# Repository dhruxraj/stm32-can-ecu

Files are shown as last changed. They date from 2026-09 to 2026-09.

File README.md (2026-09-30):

# STM32 CAN ECU – development board (rev A)

A compact, "ECU-style" CAN node for learning and prototyping automotive-type embedded software. It has an STM32G4 MCU, a CAN transceiver with protection and switchable termination, a 6-axis IMU, a protected 8-18 V supply, SWD, a UART, LEDs and buttons.

Two or more identical boards talk to each other over CANH/CANL/GND. Each board broadcasts:

* a heartbeat,
* IMU data,
* supply voltage,
* diagnostics.

Each board also supervises its peers.

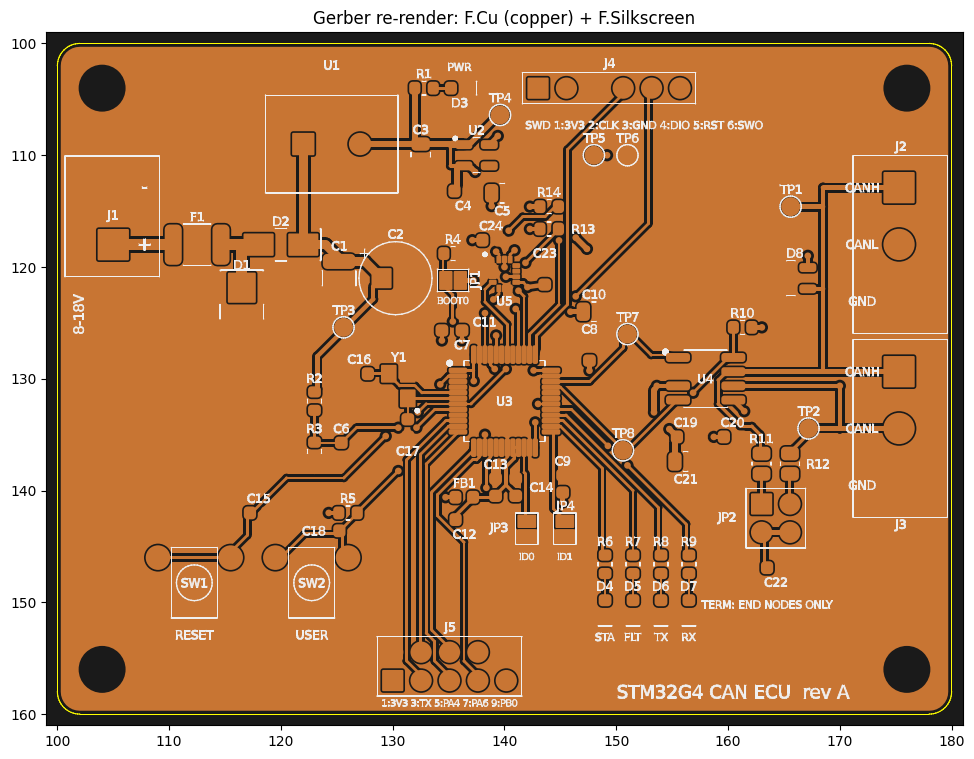
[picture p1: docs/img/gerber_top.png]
PCB


## Quick facts

| | |
|---|---|
| MCU | **STM32G431CBT6** (Cortex-M4F 170 MHz, 128 KB flash, 32 KB RAM, LQFP48) |
| CAN transceiver | **NXP TJA1051T/3** (5 V VCC, 3.3 V VIO), PESD1CAN ESD, split termination on jumper |
| IMU | **ST LSM6DS3TR-C** (accel ±4 g, gyro ±500 dps, I2C 0x6A) |
| Supply | **8-18 V DC** (12 V nominal): PTC + TVS + reverse-polarity diode → RECOM R-78E5.0-0.5 (5 V) → AP2112K-3.3 LDO |
| Power | ≈ 0.35 W typical, < 0.85 W worst case (≈ 28 mA typical / 67 mA worst case at 12 V) |
| PCB | **80 × 60 mm, 4 layers** (signal / GND / 3V3 / signal), 1.6 mm, 4 × M3 |
| CAN | classic CAN 500 kbit/s, 11-bit IDs, counter + CRC-8 on every frame |
| Est. BOM cost | ≈ USD 19 components per board (qty 10, rough estimate) + PCB |
| Tools | KiCad 7/8/9, STM32CubeIDE or CMake + arm-none-eabi-gcc, ST-LINK |

## Repository layout

```
README.md                  this file
docs/                      all documentation (start with BRINGUP.md when your boards arrive)
hardware/kicad/            KiCad project: CAN_ECU.kicad_pro / .kicad_sch / .kicad_pcb + libraries
hardware/fab/              preview Gerbers, drill files, BOM.csv, CPL_top.csv
hardware/gen/              Python generators + independent checkers (how rev A was produced)
firmware/                  STM32Cube HAL firmware (CMake / CubeIDE), host unit tests
tools/                     can_ecu.dbc, Python decoder/monitor (python-can)
```

## Architecture

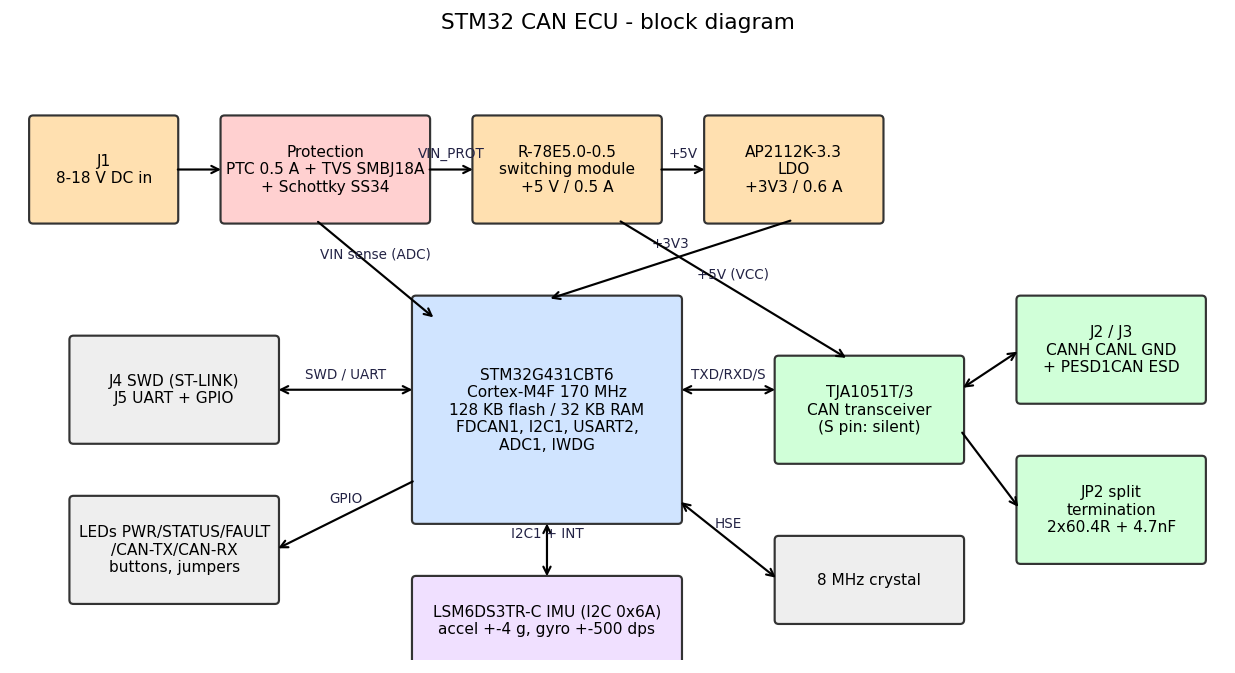
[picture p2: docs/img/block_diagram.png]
block diagram


| Document | Content |
|---|---|
| [docs/DESIGN_NOTES.md](docs/DESIGN_NOTES.md) | architecture, all design decisions, circuit calculations, **assumptions list**, limitations, future work |
| [docs/POWER_CALCS.md](docs/POWER_CALCS.md) | per-rail current budget, regulator dissipation, input current, total power |
| [docs/PIN_MAPPING.md](docs/PIN_MAPPING.md) | all 48 MCU pins, alternate functions, connector and jumper pinouts |
| [docs/COMPONENTS.md](docs/COMPONENTS.md) | component list and footprint list (with **VERIFY** notes) |
| [docs/PCB_LAYOUT.md](docs/PCB_LAYOUT.md) | stack-up, rules, placement and routing strategy |
| [docs/CAN_PROTOCOL.md](docs/CAN_PROTOCOL.md) | IDs, byte layouts, scaling, rates, status bits, counter/CRC, fault bits |
| [docs/FIRMWARE.md](docs/FIRMWARE.md) | module structure, scheduler, robustness features, building, programming |
| [docs/MANUFACTURING.md](docs/MANUFACTURING.md) | fab spec, how to produce/order Gerbers, assembly notes, cost |
| [docs/BRINGUP.md](docs/BRINGUP.md) | step-by-step bring-up, **two-board CAN test**, troubleshooting |
| [docs/TEST_CHECKLIST.md](docs/TEST_CHECKLIST.md) | per-board test sheet |
| [docs/VALIDATION_REPORT.md](docs/VALIDATION_REPORT.md) | results of all automated checks and what could not be checked |

## Hardware overview

* **Power input.** J1 (5.08 mm screw terminal) → F1 PTC 0.5 A → D1 SMBJ18A TVS → D2 SS34 series Schottky → 10 µF + 47 µF → R-78E 5 V module → AP2112K 3.3 V LDO. The MCU's analog supply (VDDA/VREF+) is filtered by FB1. The PWR LED is on +5 V. VIN is measured by the MCU (PA0).
* **MCU.** STM32G431CBT6 with an 8 MHz crystal (PLL 170 MHz) and 100 nF per VDD pin plus 4.7 µF bulk. It has a reset button and SWD header, BOOT0 pull-down plus jumper, and two node-ID jumpers. Unused pins are left unconnected and set to analog.
* **CAN.** FDCAN1 (PA11/PA12) → TJA1051T/3 → PESD1CAN → J2/J3 (1 CANH, 2 CANL, 3 GND, paralleled). JP2 enables the 2 × 60.4 Ω split termination with 4.7 nF to GND. The transceiver's S pin holds it silent until the firmware is ready. Test pads: TP1 CANH, TP2 CANL, TP7 CAN_TX, TP8 CAN_RX.
* **IMU.** LSM6DS3TR-C on I2C1 (PA15/PB7, 4k7 pull-ups), with INT1/INT2 wired to PB5/PB9.
* **User interface.** LEDs STATUS/FAULT/CAN-TX/CAN-RX plus PWR; RESET and USER buttons; J5 2×5 header (3.3 V UART + 5 GPIO/ADC).

## Software overview

* **Firmware.** Bare-metal C using the STM32Cube HAL. A cooperative scheduler runs 10/20/100/1000 ms tasks.
* **CAN.** Interrupt-driven FDCAN RX into a ring buffer, with hardware ID filters and automatic bus-off recovery.
* **Protocol.** IMU data at 50 Hz, heartbeat and board data at 10 Hz, diagnostics at 1 Hz. Every frame carries a rolling counter and a CRC-8.
* **Supervision.** Peer heartbeat timeout of 300 ms. Node states are INIT/RUN/DEGRADED/FAULT, with 13 fault bits (active + latched).
* **Robustness.** Independent watchdog (~1 s), reset-cause reporting, crystal-failure fallback, IMU fault detection with auto re-init.
* **PC side.** `tools/can_monitor.py` (python-can) decodes and verifies all frames and can send commands. `tools/can_ecu.dbc` works in any CAN analyzer.

## Getting started

### 1. Open the design in KiCad

1. Install KiCad 7, 8 or 9.
2. Copy/unzip the project and open **`hardware/kicad/CAN_ECU.kicad_pro`**.
   * Symbols and footprints come from the project-local libraries `CAN_ECU.kicad_sym` / `CAN_ECU.pretty`. They are registered in the project's `sym-lib-table` / `fp-lib-table`, so no library setup is needed.
   * KiCad 8/9 will say the files were made by an older version. Accept; saving converts them.
3. **Schematic:** open the schematic editor and run **Inspect → Electrical Rules Checker**.
4. **PCB:**
   1. Open the PCB editor and press **B** (Fill All Zones). The planes and pours are stored unfilled.
   2. Run **Inspect → Design Rules Checker**. Enable "Test for parity between PCB and schematic".
   3. Use **View → 3D Viewer** for a sanity check. 3D models are not linked, so only footprint outlines appear.

### 2. Order boards

See [docs/MANUFACTURING.md](docs/MANUFACTURING.md). In short:

1. Fill the zones, run DRC and plot Gerbers + drill files from KiCad.
2. Order a 4-layer, 1.6 mm board with ENIG finish.
3. Buy the parts from `hardware/fab/BOM.csv`. Verify the footprints marked **VERIFY** in docs/COMPONENTS.md first.

### 3. Build and flash the firmware

```bash
cd firmware && ./scripts/fetch_st_drivers.sh
cmake -B build -DCMAKE_TOOLCHAIN_FILE=cmake/gcc-arm-none-eabi.cmake && cmake --build build
STM32_Programmer_CLI -c port=SWD mode=UR -w build/can_ecu.hex -v -rst
```

Connect the ST-LINK to J4:

| J4 pin | Signal |
|---|---|
| 1 | VDD (sense) |
| 2 | SWCLK |
| 3 | GND |
| 4 | SWDIO |
| 5 | NRST |
| 6 | SWO |

The board must be powered from J1 while you program it. For the console, use a 3.3 V USB-UART on J5 (pin 3 TX, pin 4 RX, pin 2 GND) at 115200 8N1. CubeIDE instructions are in [docs/FIRMWARE.md](docs/FIRMWARE.md).

### 4. Connect two boards and test CAN

1. Board A: JP3 and JP4 open (**node 0**). Board B: **JP3 closed (node 1)**.
2. On a 2-node bus both boards are bus ends, so **fit both JP2 shunts (1-3 and 2-4) on both boards**. With power off, CANH-CANL must measure ≈ 60 Ω.
3. Wire J2/J3 pin 1-1 (CANH), 2-2 (CANL), 3-3 (GND), using a twisted pair for CANH/CANL.
4. Power both boards (8-18 V).
5. Check the result:
   * Both STATUS LEDs flash at 1 Hz (RUN) and the CAN-TX/RX LEDs flicker.
   * Each UART prints `peer node X online`, and the status line shows the peer's accelerometer values.
   * Pressing USER on one board makes the other blink fast for 3 s.
   * Unplugging the cable gives `PEER_TIMEOUT` (DEGRADED) within 300 ms; the boards recover automatically when you plug it back in.
6. With a USB-CAN adapter, run `python3 tools/can_monitor.py -i socketcan -c can0`. Expect about 121 frames/s per node with zero CRC or counter errors.

The full procedure, expected values and scope checks are in [docs/BRINGUP.md](docs/BRINGUP.md).

## Troubleshooting (short)

| Symptom | Check |
|---|---|
| One board alone shows DEGRADED + `CAN_PASSIVE` | Normal: CAN needs a second node to acknowledge frames. |
| Two boards don't see each other | Node IDs must differ. Check CANH↔CANH / CANL↔CANL wiring, the GND wire, and that termination measures ≈ 60 Ω. |
| `HSI16 FALLBACK` printed | Crystal not starting: check the joints and C16/C17. |
| `IMU_COMM` fault / WHO_AM_I 0x00 | IMU (LGA) soldering, or pull-ups R13/R14. |
| No +3V3 | U2 orientation; a short on +3V3. |
| ST-LINK can't connect | Use "connect under reset"; make sure JP1 (BOOT0) is open. |

More in [docs/BRINGUP.md](docs/BRINGUP.md#5-troubleshooting).

## Validation status (honest summary)

* **PCB design-rule check** (independent checker, 0.2 mm rules): **0 violations, 0 unconnected nets**. Both planes are continuous, and there are no courtyard overlaps.
* **Generated KiCad files re-parsed:**
  * S-expression syntax is valid.
  * The schematic netlist equals the PCB netlist for all 46 nets.
  * The ERC subset passes, and there are no silkscreen collisions.
* **Firmware:** 60 host unit checks pass (protocol, diagnostics, IMU conversion). All sources compile cleanly against a HAL stub, and the Python decoder matches the C golden frames.
* **Not verified here:**
  * KiCad's own ERC/DRC and zone fill (KiCad was not available).
  * A real arm-none-eabi build against the ST HAL.
  * Operation on hardware.
  * Footprints marked VERIFY.

  Details and remaining risks are in [docs/VALIDATION_REPORT.md](docs/VALIDATION_REPORT.md) and [docs/DESIGN_NOTES.md](docs/DESIGN_NOTES.md#4-assumptions-and-items-that-were-not-fully-verified).

## Limitations

This is a development board, **not an automotive-qualified ECU**:

* No ISO 7637 / ISO 16750 load-dump protection.
* No CAN common-mode choke.
* No USB in rev A: it conflicts with the CAN pins on this MCU.
* A single CAN channel.
* The counter/CRC/state machine is AUTOSAR-*inspired*, not compliant.

See [docs/DESIGN_NOTES.md](docs/DESIGN_NOTES.md#5-limitations-of-rev-a).

## Future improvements

* A 2-FDCAN MCU with USB-C.
* A discrete wide-input buck with ideal-diode reverse protection and load-dump rating.
* CAN FD, and a CAN bootloader.
* A CMC footprint.
* UDS-style diagnostics.

See [docs/DESIGN_NOTES.md](docs/DESIGN_NOTES.md#6-future-improvements).

## License

This project uses separate licenses for hardware, software, and documentation.

- **Hardware:** CERN-OHL-P-2.0
- **Firmware and software tools:** MIT License
- **Documentation:** CC BY 4.0

See the corresponding `LICENSE-*` files in the repository for the
complete license terms.

Third-party components retain their original licenses.

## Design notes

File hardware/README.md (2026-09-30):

# Hardware

```
hardware/
  kicad/     KiCad project (open CAN_ECU.kicad_pro) + project symbol/footprint libraries
  fab/       preview Gerbers, drill files, BOM.csv, CPL_top.csv (regenerate from KiCad for ordering)
  gen/       Python generators - the design "source code"
```

`gen/` is how every hardware file in this project was produced. KiCad itself was not available while the files were generated, so they were written by these scripts.

| Script | Purpose |
|---|---|
| `design.py` | parts, values, part numbers and the pin→net netlist (single source of truth) |
| `lib.py` | symbol and footprint definitions |
| `board.py` | board outline and component placement |
| `routing.py` | hand routes, plane fan-out and a constrained router for the low-speed nets |
| `write_kicad.py` | writes the `.kicad_sch/.kicad_pcb/.kicad_pro/.kicad_sym/.pretty` files |
| `checks.py` | independent DRC, connectivity and plane-continuity checks |
| `validate_files.py` | re-parses the written files: syntax, schematic↔PCB netlist, ERC subset, silkscreen |
| `fab.py` | Gerber/Excellon/BOM/CPL + Gerber re-render |
| `gen_docs.py` | pin map, component list, validation report, figures |

Regenerate everything (Python 3.10+, numpy, scipy, matplotlib): `cd hardware/gen && ./build_all.sh`

**Recommended workflow once you own the design:** open the project in KiCad and continue there. KiCad becomes the source of truth from that point, and the generators are then only a record of how rev A was made. Do not mix the two workflows: re-running the generators overwrites manual KiCad edits.

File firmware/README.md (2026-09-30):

# STM32 CAN ECU firmware

STM32G431CBT6 · STM32Cube HAL · C11 · no RTOS. Full documentation is in [`../docs/FIRMWARE.md`](../docs/FIRMWARE.md). The CAN protocol is described in [`../docs/CAN_PROTOCOL.md`](../docs/CAN_PROTOCOL.md).

```bash
./scripts/fetch_st_drivers.sh
cmake -B build -DCMAKE_TOOLCHAIN_FILE=cmake/gcc-arm-none-eabi.cmake -DCMAKE_BUILD_TYPE=Debug
cmake --build build
STM32_Programmer_CLI -c port=SWD mode=UR -w build/can_ecu.hex -v -rst
make -C tests            # host unit tests
```

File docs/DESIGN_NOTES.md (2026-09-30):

# Design notes, decisions and assumptions

## 1. Architecture

block diagram

The board is a small "ECU-style" CAN node:

* **Power:** 8-18 V DC input (12 V nominal). The input is protected by a resettable PTC fuse, a TVS diode and a series Schottky diode. A RECOM R-78E5.0-0.5 switching module makes +5 V. An AP2112K LDO makes +3V3 from +5 V. A ferrite bead and extra capacitors give a filtered +3V3A for the MCU's analog supply (VDDA / VREF+).
* **MCU:** STM32G431CBT6 in LQFP48. It has a Cortex-M4F at 170 MHz, 128 KB flash, 32 KB RAM and one FDCAN (it can be used as classic CAN). It runs from an 8 MHz crystal with the PLL at 170 MHz.
* **CAN:** NXP TJA1051T/3 transceiver. Its VCC is +5 V and its VIO is 3.3 V, so it talks directly to the MCU at 3.3 V logic. The bus has a PESD1CAN ESD diode and a jumper-selectable split termination. Two paralleled 3-pole screw terminals let you daisy-chain boards.
* **Sensor:** ST LSM6DS3TR-C 6-axis IMU on I2C1 (address 0x6A). Its two interrupt lines go to the MCU.
* **Debug and interface:**
  * SWD header in ST-LINK/Nucleo pin order, with SWO.
  * 3.3 V UART plus 5 GPIO on a 2x5 header.
  * 5 LEDs, reset and user buttons.
  * BOOT0 jumper and two node-ID jumpers.

## 2. Key decisions (and why)

| # | Decision | Reason / trade-off |
|---|---|---|
| D1 | **STM32G431CBT6** (G4, not G0) | G0B1/G0C1 also have FDCAN, but the G431 adds FPU, 170 MHz, better ADC and wide availability. The LQFP48 package is hand-solderable at 0.5 mm pitch. |
| D2 | **No USB in rev A** | FDCAN1 is only usable on PA11/PA12, which are also the USB pins. The alternative PB8/PB9 puts CAN_RX on BOOT0, a well-known boot problem. CAN has priority; a UART on J5 replaces USB. |
| D3 | **Input 8-18 V**, not 5-12 V | The CAN transceiver needs 4.5-5.5 V on VCC. A 5 V rail from a 5 V input with protection drops is not possible, and the R-78E module needs >= 7 V in. 12 V automotive-style supply is the target. 5 V input is **not supported**. |
| D4 | Switching module instead of a linear 5 V regulator | 12 V to 5 V at up to 125 mA would waste ~0.9 W in a linear regulator. The pre-certified module needs no layout-critical inductor loop, which suits a first PCB. |
| D5 | 4-layer stack (signal / GND / 3V3 / signal) | This gives a solid reference plane under every trace. It also allows short via-to-plane decoupling, better EMC and easy routing of a 0.5 mm-pitch MCU. Price difference to 2-layer is small at prototype quantities. |
| D6 | TJA1051**T/3** (VIO variant) | The pin 5 VIO gives true 3.3 V logic levels. The plain TJA1051T has pin 5 NC and 5 V RXD output, which is **not** 3.3 V-safe on every MCU pin. Order the **/3** variant. |
| D7 | S pin pulled HIGH (silent) by default | The node stays off the bus until the firmware has configured FDCAN. This avoids disturbing the bus during reset, programming or a crash. |
| D8 | Split termination on a jumper | The bus needs exactly 120 Ω at each physical end: 2 terminations per bus, 60 Ω total. The split 2x60.4 Ω + 4.7 nF to GND also filters common-mode noise (corner ≈ 1.1 MHz). A permanent 120 Ω on every board would give 40 Ω with 3 boards. |
| D9 | Classic CAN 500 kbit/s | Supported by every USB-CAN adapter and analyzer. CAN FD is possible with this MCU/transceiver later (TJA1051 is specified to 5 Mbit/s). |
| D10 | Node ID by solder jumpers | Identical firmware on all boards, no reflashing needed for a second node. |
| D11 | Label-connected single-sheet schematic | Generated programmatically and guaranteed consistent with the PCB netlist. Net labels at every pin make it easy to trace nets in KiCad (click a label to highlight the whole net). |

## 3. Circuit details and small calculations

**HSE crystal (Y1, 8 MHz, CL = 12 pF).**
C = 2 × (CL − C_stray) = 2 × (12 − ~4.5) pF ≈ 15 pF → C16/C17 = 15 pF C0G.
Check the actual crystal's CL and ESR against ST AN2867 (gm_crit margin). A different CL needs different caps.

**Reset.**
NRST has an internal pull-up (~40 kΩ), plus C15 = 100 nF to GND and the SW1 pushbutton. The SWD header carries NRST (pin 5) so the debugger can reset the MCU.

**BOOT0.**
PB8-BOOT0 is pulled down by R4 (10 kΩ) and boots from flash. Closing JP1 enables the ROM bootloader, which the factory option bytes sample (nSWBOOT0 = 1).

**VBAT.**
Tied to +3V3 with its own 100 nF (no RTC battery).

**VDDA / VREF+.**
+3V3 → FB1 (600 Ω @ 100 MHz) → +3V3A with C12 1 µF + C13/C14 100 nF.

**VIN sense.**
R2 100 kΩ / R3 15 kΩ gives a ratio of 7.667. 18 V → 2.35 V at PA0; 25 V → 3.26 V. C6 100 nF gives τ = 1.3 ms. The ADC is referenced to the measured VREFINT, so the result is ratiometric-corrected.

**I2C pull-ups.**
4k7 at 400 kHz with an estimated ≤ 50 pF bus gives t_r ≈ 0.85 × 4.7 kΩ × 50 pF ≈ 0.2 µs. This is below the 0.3 µs Fast-mode limit.

**LED currents.**
(3.3 V − ~2.0 V) / 680 Ω ≈ 1.9 mA, which is enough for modern high-efficiency 0603 LEDs. The power LED gets (5 V − 2 V) / 1k5 = 2 mA.

**CAN ESD.**
PESD1CAN (SOT-23) sits close to the connectors, and the CAN traces pass the diode before reaching the transceiver.

**Reverse polarity.**
The series Schottky D2 blocks reverse voltage. The TVS D1 sits before D2 and is forward-biased on a reversed input, acting as a crowbar. The resulting fault current trips the PTC F1 (hold 0.5 A) within about a second. The board survives, but the supply sees a short until the PTC trips.

## 4. Assumptions and items that were NOT fully verified

| # | Item | Status / action |
|---|---|---|
| A1 | LSM6DS3TR-C LGA-14 land pattern (0.5 × 0.25 mm pads) | Modelled on the typical ST recommendation. **Verify** against the current ST datasheet/TN before ordering. |
| A2 | PESD1CAN pin assignment (1, 2 = lines, 3 = common) | Symmetric device, so a 1↔2 swap is harmless. **Verify pin 3** = common. |
| A3 | R-78E5.0-0.5 pin pitch 2.54 mm and body offset | The keep-out is reserved ±6.5 mm around the pin row. **Verify** against the RECOM drawing. |
| A4 | Screw terminal MPNs (Phoenix 1729128 / 1729131) and hole sizes | **Verify** with the part you buy; any 5.08 mm-pitch terminal with 1.3 mm drill is fine. |
| A5 | Crystal CL 12 pF, 3225 package | Choose a crystal with CL 10-12 pF and ESR ≤ 80 Ω, and recompute C16/C17. |
| A6 | I2C timing 0x10320309 (400 kHz @ HSI16) | Taken from the RM0440 timing example. Verify with CubeMX or measure SCL. |
| A7 | PTC hold 0.5 A / ≥ 30 V rating | Any 1812 PTC with I_hold ≈ 0.5 A and V_max ≥ 30 V. |
| A8 | TVS SMBJ18A clamp 29.2 V @ Ipp vs. R-78E abs. max input | The module is protected against moderate transients only. **Not rated for ISO 7637 / ISO 16750 load dump.** |
| A9 | STM32 current at 170 MHz ≈ 30-40 mA | Datasheet typical run current plus peripherals. The design budget is 100 mA on +3V3. |
| A10 | KiCad file format | Written as KiCad 7 files (opens in KiCad 7/8/9). Not opened in KiCad during generation. See VALIDATION_REPORT.md. |

## 5. Limitations of rev A

* The board is not qualified for vehicles. It has no ISO 7637-2 / ISO 16750-2 load-dump or cold-crank design, no reverse-battery MOSFET and no AEC-Q parts required.
* There is no CAN common-mode choke. One can be added for EMC-critical use.
* There is no USB (see D2). The UART needs a 3.3 V USB-UART adapter.
* Only one CAN channel (the STM32G431 has one FDCAN).
* The E2E-style counter/CRC and state machine are *automotive-inspired*. They are **not** AUTOSAR E2E or ISO 26262 compliant.
* The IMU is not mechanically isolated. Board flex or screw torque can shift the accelerometer offset slightly.

## 6. Future improvements

* Rev B MCU with 2+ FDCAN and separate USB (e.g. STM32G474 / G0B1): gives USB-C device and a second CAN channel.
* Discrete buck (e.g. LMR51420-class) with a reverse-polarity P-FET ideal diode, load-dump TVS and wider 6-36 V input.
* CAN common-mode choke plus split-termination DNP options, and optional CAN FD bit timing (2 Mbit/s data phase).
* EEPROM or option bytes for node configuration, CAN bootloader for field updates, UDS-like diagnostic services.
* Mount the IMU at the board centroid with a stiffening keep-out, and add a temperature compensation table.

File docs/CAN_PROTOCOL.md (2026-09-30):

# CAN protocol (application layer)

Machine-readable versions: `tools/can_ecu.dbc` (all messages, all 4 node IDs) and `tools/canp.py` (Python decoder, identical to `firmware/Core/Src/can_protocol.c`).

## Physical / data link

| Item | Value |
|---|---|
| Bit rate | 500 kbit/s, classic CAN 2.0A (11-bit IDs), no remote frames |
| Bit timing (170 MHz PCLK1) | prescaler 17, TSEG1 15, TSEG2 4, SJW 4 → 20 tq, **sample point 80 %** |
| Termination | 120 Ω at both physical ends (JP2 fitted on those two boards only) |
| Transceiver | TJA1051T/3, VCC 5 V, VIO 3.3 V, S pin = silent while MCU not ready |
| Connector | J2 / J3: 1 = CANH, 2 = CANL, 3 = GND (paralleled, for daisy-chaining) |

## Identifiers

`ID = 0x100 + (node << 4) + message`, node = 0..3 from jumpers JP3/JP4.

| Message | Offset | Node 0 | Node 1 | Node 2 | Node 3 | Period | Direction |
|---|---:|---:|---:|---:|---:|---:|---|
| HEARTBEAT | 0 | 0x100 | 0x110 | 0x120 | 0x130 | 100 ms | ECU → bus |
| ACCEL | 1 | 0x101 | 0x111 | 0x121 | 0x131 | 20 ms | ECU → bus |
| GYRO | 2 | 0x102 | 0x112 | 0x122 | 0x132 | 20 ms | ECU → bus |
| BOARD | 3 | 0x103 | 0x113 | 0x123 | 0x133 | 100 ms | ECU → bus |
| DIAG | 4 | 0x104 | 0x114 | 0x124 | 0x134 | 1000 ms | ECU → bus |
| COMMAND to node n | - | 0x0F0 | 0x0F1 | 0x0F2 | 0x0F3 | event | any → node |
| COMMAND broadcast | - | 0x0FF | | | | event | any → all |

Lower ID means higher priority: commands win arbitration over data, and heartbeats over sensor data of the same node.

Bus load per node is 121 frames/s (10 + 50 + 50 + 10 + 1). At ≤ 130 bits per 8-byte frame including worst-case bit stuffing, that is ≈ 16 kbit/s ≈ **3 % of 500 kbit/s**. Four nodes use about 13 %.

## Common frame rules

* **DLC** = 8 always. Frames with another DLC are rejected and counted as errors.
* **Byte order:** little-endian (Intel). Signed values are two's complement.
* **Byte 6:** bits 0-3 are the **rolling counter** (0…15, +1 per message ID). Bits 4-7 are the **status nibble**:
  * bit 4 `DATA_VALID`
  * bit 5 `SENSOR_FAULT`
  * bit 6 `DEGRADED`
  * bit 7 reserved
* **Byte 7:** **CRC-8 SAE J1850** (poly 0x1D, init 0xFF, final XOR 0xFF). It is computed over `[ID & 0xFF, (ID >> 8) & 0x07, byte0 … byte6]`, so the ID is protected as well. Check value: CRC("123456789") = 0x4B.
* **Receiver checks** (`canp_check()`):
  * DLC == 8, then CRC.
  * Counter equal to the previous one → *repeated/stale* frame, rejected.
  * Counter jump → frames lost, accepted but counted.
  * CRC, DLC or repeat errors set fault `CAN_E2E` for 1 s.

> This counter + CRC scheme is inspired by AUTOSAR E2E profiles. It is **not** an implementation of any AUTOSAR E2E profile and is not safety-certified.

## Message layouts

### HEARTBEAT (0x100 + node·16), 100 ms

| Byte | Signal | Type | Unit / values |
|---|---|---|---|
| 0 | node_id | u8 | 0..3 |
| 1 | state | u8 | 0 INIT, 1 RUN, 2 DEGRADED, 3 FAULT |
| 2-3 | faults | u16 | active fault bits (table below) |
| 4 | peers_alive | u8 | bit n = heartbeat of node n received within 300 ms |
| 5 | fw_version | u8 | major << 4 \| minor (0x10 = 1.0) |
| 6 | counter / status | | status bit 6 = DEGRADED |
| 7 | CRC | | |

### ACCEL (+1) and GYRO (+2), 20 ms

| Byte | Signal | Type | Scaling | Range |
|---|---|---|---|---|
| 0-1 | X | s16 | ACCEL: 1 mg/bit; GYRO: 0.1 °/s/bit | ±4000 mg; ±500 °/s |
| 2-3 | Y | s16 | as above | |
| 4-5 | Z | s16 | as above | |
| 6 | counter / status | | DATA_VALID, SENSOR_FAULT | |
| 7 | CRC | | | |

The sensor is sampled at 104 Hz ODR and read every 20 ms. The firmware converts the raw sensor LSBs to these physical units (0.122 mg/LSB, 17.5 mdps/LSB). When the IMU is faulty, frames keep being sent (last values, `DATA_VALID` = 0, `SENSOR_FAULT` = 1), so receivers can tell "sensor fault" from "node lost".

### BOARD (+3), 100 ms

| Byte | Signal | Type | Scaling |
|---|---|---|---|
| 0-1 | vin | u16 | 1 mV/bit |
| 2-3 | imu_temp | s16 | 0.01 °C/bit |
| 4-5 | uptime | u16 | 1 s/bit (wraps at 65535 s) |

### DIAG (+4), 1000 ms

| Byte | Signal | Meaning |
|---|---|---|
| 0 | TEC | FDCAN transmit error counter |
| 1 | REC | FDCAN receive error counter |
| 2 | proto_flags | bit0 error-warning, bit1 error-passive, bit2 bus-off, bits 3-5 last error code (LEC) |
| 3 | busoff_count | saturating at 255 |
| 4 | e2e_errors | received CRC/DLC/repeat errors since last clear (saturating) |
| 5 | reset_cause | 0 unknown, 1 power-on/BOR, 2 pin, 3 software, 4 IWDG, 5 WWDG, 6 low-power, 7 option-byte |

### COMMAND (0x0F0 + target, or 0x0FF broadcast)

| Byte | Signal | Values |
|---|---|---|
| 0 | command | 1 IDENTIFY (STATUS LED blinks fast for 3 s), 2 CLEAR_FAULTS (clear latched fault history) |
| 1 | source node | 0..3, 0x0F = PC tool |
| 2 | argument | reserved (0) |
| 3-5 | reserved | 0 |
| 6-7 | counter / CRC | as for all frames |

A short press of the USER button sends IDENTIFY broadcast. A long press (≥ 2 s) clears local faults and broadcasts CLEAR_FAULTS.

## Fault bits (heartbeat bytes 2-3)

| Bit | Name | Set when | Cleared when |
|---:|---|---|---|
| 0 | IMU_COMM | WHO_AM_I wrong / I2C error | IMU re-init succeeds (retried every 1 s) |
| 1 | IMU_DATA | 50 identical samples (stuck) or all-zero accel | data plausible again |
| 2 | CAN_BUSOFF | FDCAN bus-off (**critical → state FAULT**) | automatic recovery done |
| 3 | CAN_PASSIVE | error-passive (e.g. alone on the bus, no ACK) | counters decrease |
| 4 | PEER_TIMEOUT | a peer seen before sends no heartbeat for 300 ms | peer back |
| 5 | CAN_E2E | CRC / DLC / repeated-counter error received | 1 s without errors |
| 6 | VIN_LOW | VIN < 7.5 V | VIN > 7.8 V |
| 7 | VIN_HIGH | VIN > 18.5 V | VIN < 18.0 V |
| 8 | HSE | crystal failed (CSS) → running from HSI16 ±1 % | reset |
| 9 | WDG_RESET | last reset by watchdog (latched only) | CLEAR_FAULTS |
| 10 | CAN_TX_OVF | TX FIFO full, frame dropped | 1 s without overflow |
| 11 | MCU_TEMP | die temperature > 100 °C | < 100 °C |
| 12 | ID_CONFLICT | a frame with our own node ID was received | CLEAR_FAULTS/reset |

**State machine:**

* INIT: stays in INIT for at least 200 ms and until all drivers are initialised.
* FAULT: if any critical fault is active.
* DEGRADED: if any other fault is active.
* RUN: otherwise.

"Latched" faults (history since power-up or the last CLEAR_FAULTS) are shown by a slow FAULT-LED blink.

## Example frames (golden vectors, verified in C and Python)

```
0x110  01 01 00 00 01 10 03 3A   HEARTBEAT node 1, RUN, no faults, peers 0x01, fw 1.0, counter 3, CRC 0x3A
0x101  0C 00 DD FF E6 03 17 7E   ACCEL node 0: X = 12 mg, Y = -35 mg, Z = 998 mg, DATA_VALID, counter 7
```

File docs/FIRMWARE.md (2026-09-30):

# Firmware

`firmware/` is an STM32Cube HAL project in C11 for the STM32G431CBT6. No RTOS is used.

## Module structure

| File | Responsibility |
|---|---|
| `Core/Src/main.c` | Start-up sequence, clock tree (HSE→PLL 170 MHz, HSI16 fallback, clock-security system), reset-cause capture, watchdog, main loop |
| `Core/Src/board.c` / `board.h` | Pin map, GPIO init (unused pins → analog), LEDs, button, node-ID jumpers, transceiver S pin, ADC (VIN, VREFINT, die temperature) |
| `Core/Src/can.c` / `can.h` | FDCAN1: 500 kbit/s timing, RX filters, interrupt RX into a lock-free ring buffer, TX FIFO queue, error counters, **bus-off recovery** |
| `Core/Src/can_protocol.c` / `.h` | Pure-C protocol: IDs, payload packing, rolling counter, CRC-8, receive checks, peer timeout (host unit-tested) |
| `Core/Src/imu.c` / `imu.h` | LSM6DS3TR-C: WHO_AM_I, soft reset, configuration, burst read, unit conversion, stuck/implausible detection, automatic re-init |
| `Core/Src/diagnostics.c` / `.h` | Fault bits, active/latched handling, VIN hysteresis, node state machine (host unit-tested) |
| `Core/Src/app.c` / `app.h` | Cooperative scheduler, CAN message handling, commands, LED patterns, button, UART status output |
| `Core/Src/debug.c` | USART2 115200 8N1 console; `printf` via `_write` |
| `Core/Src/stm32g4xx_it.c`, `stm32g4xx_hal_msp.c` | Interrupt handlers (SysTick, FDCAN1_IT0, NMI/CSS, faults) and peripheral clock/pin/NVIC setup |
| `Core/Inc/stm32g4xx_hal_conf.h` | HAL module selection, HSE_VALUE = 8 MHz |
| `STM32G431CBTX_FLASH.ld` | Linker script (128 KB flash, 32 KB RAM) |
| `CMakeLists.txt`, `cmake/` | arm-none-eabi-gcc build |
| `tests/` | Host unit tests + compile check of all sources against HAL stubs |

## Scheduler and timing

The scheduler runs on the 1 ms `HAL_GetTick()`, cooperatively and without blocking. All HAL calls have timeouts of 20 ms or less.

| Period | Work |
|---|---|
| 10 ms | drain CAN RX queue (max 16 frames), FDCAN status + bus-off recovery, fault flags, state machine, button, LEDs |
| 20 ms | IMU read (or re-init attempt once per second when faulty), ACCEL + GYRO frames |
| 100 ms | VIN measurement, peer heartbeat supervision (300 ms timeout), HEARTBEAT + BOARD frames |
| 1000 ms | MCU temperature, DIAG frame, one UART status line |

## Robustness features ("automotive-style", not certified)

* **Watchdog:**
  * The IWDG runs at about 1 s (LSI/32, reload 1000) and is frozen while the debugger halts the core.
  * It is refreshed only if the 10 ms task ran within the last 100 ms. A stuck loop, a HardFault or `Error_Handler()` therefore causes a reset.
  * A watchdog reset is latched as fault `WDG_RESET` and reported in DIAG.
* **Reset cause:** read from RCC_CSR at start-up and sent in DIAG.
* **Clock monitoring:**
  * If the crystal does not start, the PLL is built from HSI16 at the same 170 MHz, so the CAN timing is unchanged.
  * The clock security system (NMI) catches a crystal failure at run time.
  * Both cases set fault `HSE`, because HSI accuracy (±1 %) is marginal for CAN.
* **CAN bus handling:**
  * RX filters accept only 0x100-0x13F plus own and broadcast commands.
  * Error-warning, error-passive and bus-off are monitored.
  * Bus-off is recovered automatically: after 100 ms the firmware clears CCCR.INIT, and the controller then waits for 128×11 recessive bits.
  * The TX FIFO fill level is checked before sending; overflow is flagged.
  * The transceiver stays silent until FDCAN is running.
* **End-to-end-style checks:** rolling counter + CRC-8 on every frame, DLC check, repeated-frame detection, lost-frame counting, 300 ms heartbeat timeout per peer, detection of a second node with the same ID.
* **Sensor faults:**
  * WHO_AM_I and register read-back at init.
  * I2C error counting.
  * Stuck-data detection (50 identical samples) and all-zero detection.
  * Automatic re-initialisation every 1 s.
  * Invalid data is still transmitted but marked `DATA_VALID = 0` / `SENSOR_FAULT = 1`.
* **Supply monitoring:** VIN is measured against VREFINT with hysteresis, and the die temperature is checked.

## LED indication

| LED | Pattern | Meaning |
|---|---|---|
| PWR (D3, green) | on | +5 V present |
| STATUS (D4, green) | 5 Hz blink | INIT |
| | 1 Hz short flash | RUN |
| | 2 Hz blink | DEGRADED |
| | off | FAULT |
| | 10 Hz for 3 s | IDENTIFY received |
| FAULT (D5, red) | on | active fault |
| | short flash every 2 s | only latched (past) faults |
| | off | no faults |
| CAN TX (D6) | flicker | frame transmitted |
| CAN RX (D7) | flicker | frame received |

## Building

### Option A - CMake + GNU Arm toolchain (Linux/macOS/Windows)

```bash
cd firmware
./scripts/fetch_st_drivers.sh        # clones ST's HAL + CMSIS from github.com/STMicroelectronics
cmake -B build -DCMAKE_TOOLCHAIN_FILE=cmake/gcc-arm-none-eabi.cmake -DCMAKE_BUILD_TYPE=Debug
cmake --build build                  # -> build/can_ecu.elf, .hex, .bin
```

Requires `arm-none-eabi-gcc` (Arm GNU Toolchain 12 or newer), CMake ≥ 3.20 and git.

### Option B - STM32CubeIDE

1. Go to **File → New → STM32 Project**, pick **STM32G431CBTx**, and choose an empty C project with the STM32Cube firmware package.
2. Delete the generated `Core/Src/main.c` and `Core/Inc/main.h`.
3. Copy every file from `firmware/Core/Inc` and `firmware/Core/Src` into the project's `Core/Inc` and `Core/Src`, overwriting `stm32g4xx_hal_conf.h`, `stm32g4xx_it.*` and `stm32g4xx_hal_msp.c`.
4. Make sure the HAL drivers for ADC, FDCAN, I2C, IWDG and UART are present in `Drivers/STM32G4xx_HAL_Driver`. Copy them from the STM32CubeG4 package if the wizard did not add them.
5. Delete CubeIDE's `syscalls.c` **or** our `_write()` in `debug.c`. Keep only one `_write`.
6. Build with Project → Build, then Run → Debug with the ST-LINK.

### Host tests (any PC with gcc)

```bash
make -C firmware/tests      # 60 unit checks (ASan/UBSan) + stub-HAL compile of every source file
python3 tools/test_tools.py # Python decoder == C golden vectors, DBC layout check
```

> **Honest status:** the protocol, diagnostics and IMU-conversion logic were compiled and unit-tested on a PC. Every other source file was compiled with `-Wall -Wextra -Werror` against a minimal HAL *stub*. The firmware was **not** built with arm-none-eabi-gcc against the real ST HAL, and not run on hardware, in the generation environment. Expect possible small compile fixes if your HAL version differs; the code avoids version-specific details (for example, `DataLength` is handled for both HAL encodings).

## Programming

1. Connect an ST-LINK V2/V3 (or a Nucleo board's ST-LINK with its CN2 jumpers removed) to **J4**:

   | J4 pin | Signal |
   |---|---|
   | 1 | VDD_TARGET (sense only) |
   | 2 | SWCLK |
   | 3 | GND |
   | 4 | SWDIO |
   | 5 | NRST |
   | 6 | SWO |

   Pin 1 is the square pad.
2. Power the board from J1 (12 V). The ST-LINK does **not** power the board.
3. Flash:
   * **STM32CubeProgrammer:** `STM32_Programmer_CLI -c port=SWD mode=UR -w build/can_ecu.hex -v -rst`
   * **OpenOCD:** `openocd -f interface/stlink.cfg -f target/stm32g4x.cfg -c "program build/can_ecu.elf verify reset exit"`
   * **CubeIDE:** Run/Debug.
4. Console: connect a 3.3 V USB-UART to J5.
   * J5 pin 3 (board TX) → adapter RX.
   * J5 pin 4 (board RX) ← adapter TX.
   * J5 pin 2 → GND.
   * Settings: 115200 8N1.

**Fallback without ST-LINK:**

1. Close JP1 (BOOT0) and reset.
2. Use STM32CubeProgrammer over UART on PA2/PA3: `-c port=/dev/ttyUSB0`. USART2 is a bootloader interface on G431 — **verify against ST AN2606 (STM32G431 section)**.
3. Open JP1 again afterwards.

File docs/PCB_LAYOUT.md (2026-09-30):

# PCB layout

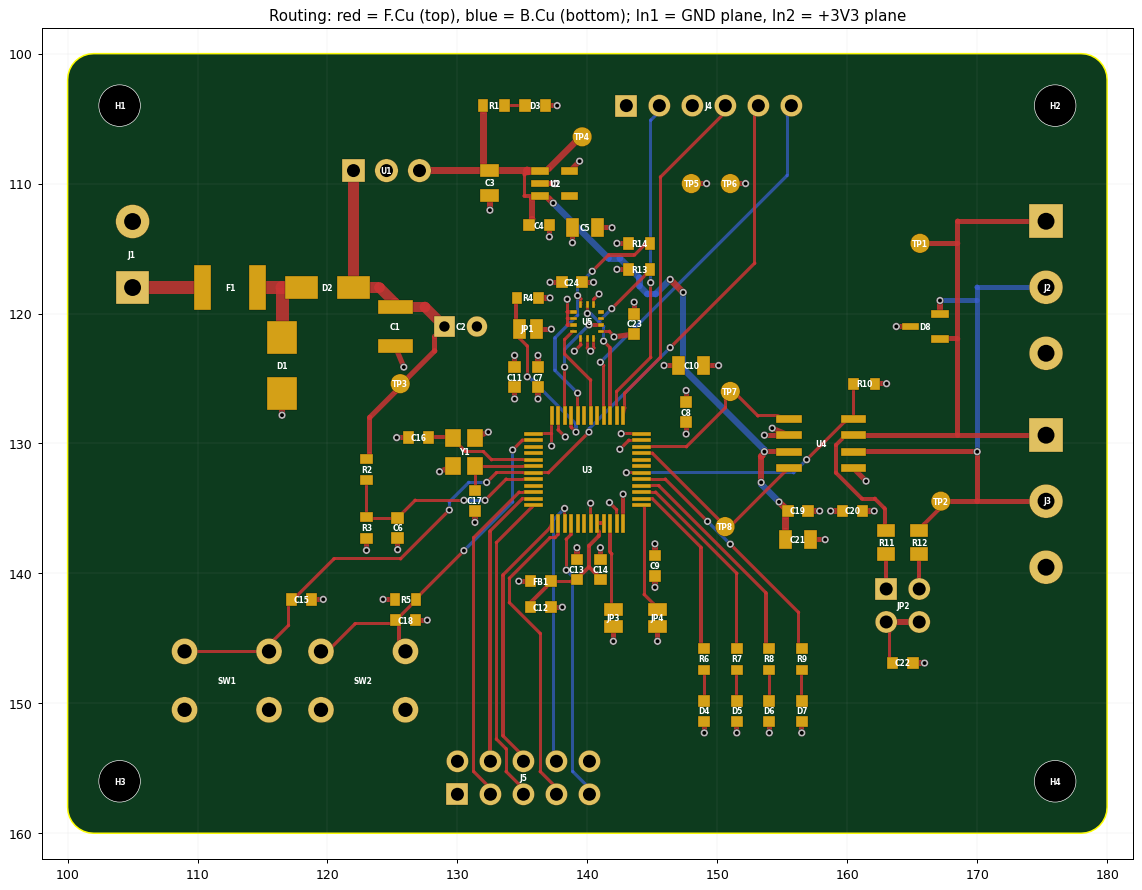
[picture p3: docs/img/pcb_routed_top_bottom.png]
routed board


| Item | Value |
|---|---|
| Size | **80 × 60 mm**, 2 mm corner radius, 4 × M3 holes (3.2 mm NPTH) at 4 mm from the edges |
| Stack-up | **4 layers, 1.6 mm, 1 oz outer / 0.5-1 oz inner** |
| Layers | F.Cu = components + signals + GND pour; **In1.Cu = solid GND plane**; **In2.Cu = +3V3 plane**; B.Cu = signals + GND pour |
| Rules | 0.20 mm clearance, 0.25 mm default track, 0.6/0.3 mm vias, 0.3 mm copper-to-edge, 0.25 mm zone clearance |
| Net classes | Default 0.25 mm; Power 0.5 mm (VIN 0.8-1.0 mm); CAN 0.4 mm |
| Assembly | all components on the top side; SMD 0603 minimum, one LGA-14 (IMU) and one 0.5 mm-pitch LQFP |

## Placement

* **Left edge:** J1 power input with F1 → D2 → C1/C2 → R-78E module in a straight left-to-right chain. The 1.0 mm / 0.8 mm VIN traces are on F.Cu, and TVS D1 sits right after the fuse.
* **Centre:** MCU (U3) with the crystal Y1 and its 15 pF caps directly left of OSC_IN/OSC_OUT (short, symmetric, over solid GND). The IMU (U5) sits just above the MCU.
* **Right edge:** CAN section.
  * U4 transceiver has TXD/RXD facing the MCU and CANH/CANL facing the connectors.
  * The ESD diode D8 and split termination R11/R12/C22/JP2 are next to the J2/J3 terminals.
  * CANH/CANL run as a pair (0.4 mm) from U4 to both connectors, over the GND plane.
* **Top:** SWD header J4 and the power LED. **Bottom:** J5 expansion header, the RESET/USER buttons and the 4 status LEDs with silkscreen labels.

## Routing approach

* **Hand-routed (explicit coordinates in `hardware/gen/routing.py`):** power chain, +5 V to the LDO, the CAN trunk to both connectors, the transceiver supply vias, and all MCU/IMU supply connections.
* **MCU supply connections:** the MCU supply pins connect *inward* to vias under the LQFP body. The escape area around the chip is then free for signals, and every VDD/VSS pin has its own via into the planes 0.2 mm below.
* **Other GND/+3V3 SMD pads:** each has its own short stub and via to the plane ("fan-out").
* **Remaining low-speed nets:** routed one at a time in a chosen priority order by a constrained grid router: 45° routing, turn and via penalties, exact clearance to real pad/track geometry. The order is crystal first, then CAN TX/RX, analog supply, IMU, SWD, LEDs, jumpers, expansion, then +5 V. Every result was checked by the independent DRC in `checks.py`.
* **Result:** 384 track segments, 103 vias, 0 clearance violations, 0 unconnected nets. Both planes are continuous for all their connections.

## Things to check in KiCad before ordering

1. Open `CAN_ECU.kicad_pcb` and press **B** (fill all zones). Then run **Inspect → Design Rules Checker**.
   * Expected result: no errors.
   * Silkscreen warnings may remain where reference texts touch other silk. Adjust them to taste.
2. Run **Inspect → Board Statistics** and check the layer stack in **Board Setup → Physical Stackup**. Set the stack-up your fab offers (e.g. JLC04161H-7628 or equivalent).
3. Look at thermal reliefs on the GND pads of J1, J2/J3 and the R-78E. KiCad's defaults (0.3 mm gap / 0.4 mm spokes) are fine for hand soldering.

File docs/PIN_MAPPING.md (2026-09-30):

# MCU pin mapping - STM32G431CBT6 (LQFP48)

Generated from `hardware/gen/design.py` (single source of truth for schematic, PCB and firmware `Core/Inc/board.h`). Pin numbers/names were checked against ST datasheet DS12589 (LQFP48 pinout). Unused pins are unconnected on the PCB and configured as analog inputs by the firmware.

| Pin | Name | Net | Function |
|---:|---|---|---|
| 1 | VBAT | +3V3 | +3V3 (no backup battery), 100 nF |
| 2 | PC13 | USER_BTN | USER button SW2 (active low, ext. 10k pull-up) |
| 3 | PC14-OSC32_IN | - | not connected (analog input) |
| 4 | PC15-OSC32_OUT | - | not connected (analog input) |
| 5 | PF0-OSC_IN | OSC_IN | HSE 8 MHz crystal Y1 |
| 6 | PF1-OSC_OUT | OSC_OUT | HSE 8 MHz crystal Y1 |
| 7 | PG10-NRST | NRST | Reset: SW1, C15 100 nF, SWD pin 5 |
| 8 | PA0 | VIN_SENSE | ADC1_IN1 - VIN sense divider 100k/15k |
| 9 | PA1 | - | not connected (analog input) |
| 10 | PA2 | UART_TX | USART2_TX (AF7) debug console -> J5.3 |
| 11 | PA3 | UART_RX | USART2_RX (AF7) debug console -> J5.4 |
| 12 | PA4 | EXP_PA4 | Expansion J5.5 (GPIO/ADC/DAC) |
| 13 | PA5 | EXP_PA5 | Expansion J5.6 |
| 14 | PA6 | EXP_PA6 | Expansion J5.7 |
| 15 | PA7 | EXP_PA7 | Expansion J5.8 |
| 16 | PB0 | EXP_PB0 | Expansion J5.9 |
| 17 | PB1 | - | not connected (analog input) |
| 18 | PB2 | - | not connected (analog input) |
| 19 | VSSA | GND | GND |
| 20 | VREF+ | +3V3A | +3V3A, 100 nF |
| 21 | VDDA | +3V3A | +3V3A (ferrite FB1 + 1 uF + 100 nF) |
| 22 | PB10 | NODE_ID0 | NODE_ID bit0 - solder jumper JP3 to GND (internal pull-up) |
| 23 | VSS | GND | GND |
| 24 | VDD | +3V3 | +3V3, 100 nF per pin + 4.7 uF bulk |
| 25 | PB11 | NODE_ID1 | NODE_ID bit1 - solder jumper JP4 to GND (internal pull-up) |
| 26 | PB12 | LED_STATUS | LED STATUS (green) via 680R |
| 27 | PB13 | LED_FAULT | LED FAULT (red) via 680R |
| 28 | PB14 | LED_CANTX | LED CAN-TX (yellow) via 680R |
| 29 | PB15 | LED_CANRX | LED CAN-RX (orange) via 680R |
| 30 | PA8 | CAN_S | CAN transceiver S (silent) - 10k pull-up, LOW = normal |
| 31 | PA9 | - | not connected (analog input) |
| 32 | PA10 | - | not connected (analog input) |
| 33 | PA11 | CAN_RX | FDCAN1_RX (AF9) <- TJA1051 RXD |
| 34 | PA12 | CAN_TX | FDCAN1_TX (AF9) -> TJA1051 TXD |
| 35 | VSS | GND | GND |
| 36 | VDD | +3V3 | +3V3, 100 nF per pin + 4.7 uF bulk |
| 37 | PA13 | SWDIO | SWDIO (J4.4) |
| 38 | PA14 | SWCLK | SWCLK (J4.2) |
| 39 | PA15 | I2C_SCL | I2C1_SCL (AF4) - IMU, 4k7 pull-up |
| 40 | PB3 | SWO | SWO trace output (J4.6) |
| 41 | PB4 | - | not connected (analog input) |
| 42 | PB5 | IMU_INT1 | IMU INT1 (accel data-ready) |
| 43 | PB6 | - | not connected (analog input) |
| 44 | PB7 | I2C_SDA | I2C1_SDA (AF4) - IMU, 4k7 pull-up |
| 45 | PB8-BOOT0 | BOOT0 | BOOT0: 10k pull-down, JP1 to 3V3 = system bootloader |
| 46 | PB9 | IMU_INT2 | IMU INT2 (spare) |
| 47 | VSS | GND | GND |
| 48 | VDD | +3V3 | +3V3, 100 nF per pin + 4.7 uF bulk |

## Alternate-function summary

| Peripheral | Signal | Pin | AF |
|---|---|---|---|
| FDCAN1 | RX | PA11 | AF9 |
| FDCAN1 | TX | PA12 | AF9 |
| I2C1 | SCL | PA15 | AF4 |
| I2C1 | SDA | PB7 | AF4 |
| USART2 | TX | PA2 | AF7 |
| USART2 | RX | PA3 | AF7 |
| SWD | SWDIO / SWCLK / SWO | PA13 / PA14 / PB3 | AF0 (reset default) |
| ADC1 | IN1 (VIN sense) | PA0 | analog |

**Why no USB:** on the STM32G431 the only FDCAN1 pin pair that does not collide with other functions here is PA11/PA12 - the same pins as USB DM/DP. The alternative FDCAN1 pins PB8/PB9 would put CAN RX on the BOOT0 pin (PB8), which is a known source of boot problems. Rev A therefore uses PA11/PA12 for CAN and provides a 3.3 V UART on J5 instead of USB.

## Connectors

### J1 - Power input (5.08 mm screw terminal)

| Pin | Net |
|---:|---|
| 1 | VIN_RAW |
| 2 | GND |

### J2 - CAN bus A (5.08 mm, 3-pole)

| Pin | Net |
|---:|---|
| 1 | CANH |
| 2 | CANL |
| 3 | GND |

### J3 - CAN bus B (5.08 mm, 3-pole, parallel to J2 for daisy-chaining)

| Pin | Net |
|---:|---|
| 1 | CANH |
| 2 | CANL |
| 3 | GND |

### J4 - SWD debug (1x6 2.54 mm, ST-LINK/Nucleo CN4 order)

| Pin | Net |
|---:|---|
| 1 | +3V3 |
| 2 | SWCLK |
| 3 | GND |
| 4 | SWDIO |
| 5 | NRST |
| 6 | SWO |

### J5 - Expansion / UART (2x5 2.54 mm)

| Pin | Net |
|---:|---|
| 1 | +3V3 |
| 2 | GND |
| 3 | UART_TX |
| 4 | UART_RX |
| 5 | EXP_PA4 |
| 6 | EXP_PA5 |
| 7 | EXP_PA6 |
| 8 | EXP_PA7 |
| 9 | EXP_PB0 |
| 10 | GND |

### JP2 - CAN termination (2x2 2.54 mm, fit 2 shunts: 1-3 and 2-4)

| Pin | Net |
|---:|---|
| 1 | TERM_H |
| 2 | TERM_L |
| 3 | TERM_MID |
| 4 | TERM_MID |

## Jumpers

| Ref | Function | Open (default) | Closed |
|---|---|---|---|
| JP1 | BOOT0 | boot from flash | ST system bootloader (UART/FDCAN/I2C/SPI) |
| JP2 | CAN termination (2 shunts) | no termination | 2 x 60.4 R split + 4.7 nF |
| JP3 | NODE_ID bit 0 (PB10) | 0 | 1 |
| JP4 | NODE_ID bit 1 (PB11) | 0 | 1 |

Node ID = JP4*2 + JP3 -> 0..3. Two boards must have **different** node IDs (e.g. board A: both open = node 0; board B: JP3 closed = node 1).

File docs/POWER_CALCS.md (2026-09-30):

# Power budget and dissipation

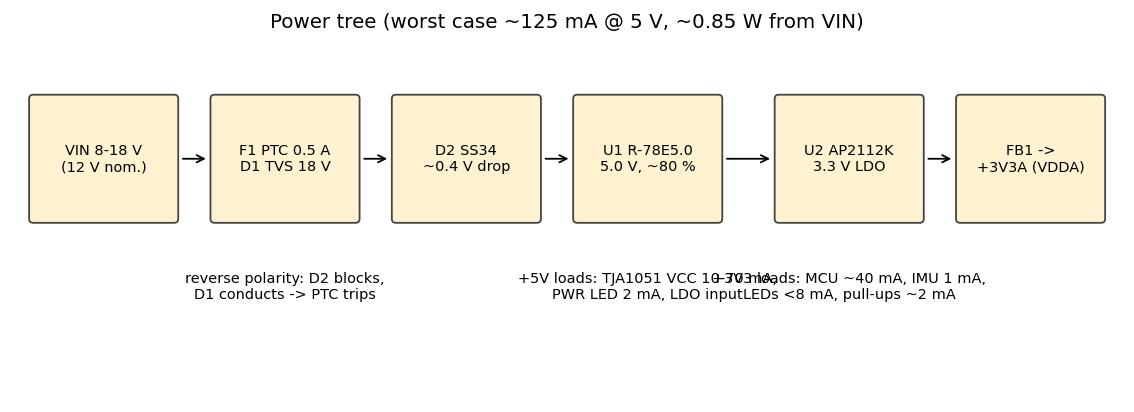
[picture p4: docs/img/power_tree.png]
power tree


## +3V3 rail (AP2112K-3.3, 600 mA rated)

| Load | Typical | Worst case | Note |
|---|---:|---:|---|
| STM32G431 @ 170 MHz, FDCAN+I2C+UART+ADC active | 30 mA | 40 mA | datasheet run-mode typical + peripherals |
| LSM6DS3TR-C (XL + G, 104 Hz high-performance) | 0.9 mA | 1.3 mA | |
| 4 status LEDs @ ~1.9 mA | 2 mA | 7.6 mA | typical = blinking duty cycle |
| I2C pull-ups (2 × 3.3 V / 4k7 when low) | 0.2 mA | 1.4 mA | |
| TJA1051 VIO, CAN_S pull-up (0.33 mA when S low), button pull-up | 0.5 mA | 1.0 mA | |
| **Total +3V3** | **≈ 34 mA** | **≈ 52 mA** | design budget 100 mA |

LDO dissipation, which scales with (5.0 − 3.3) V × I:

* At the 52 mA worst-case load: **88 mW**.
* At the 100 mA budget: **170 mW**.

With θJA ≈ 250 °C/W (SOT-23-5 on a 4-layer board, conservative) the temperature rise is +22 °C at worst case and +43 °C at the 100 mA budget. Both are fine.

## +5V rail (R-78E5.0-0.5, 500 mA rated)

| Load | Typical | Worst case | Note |
|---|---:|---:|---|
| TJA1051 VCC | 15 mA | 70 mA | 10 mA recessive / 50 typ-70 max mA dominant; typical at ~15 % bus load; worst = continuous dominant (bus fault) |
| Power LED D3 | 2 mA | 2 mA | |
| AP2112K input (= +3V3 load + 55 µA Iq) | 34 mA | 52 mA | |
| **Total +5V** | **≈ 51 mA** | **≈ 124 mA** | ≈ 25 % of module rating |

P_5V: typical 0.26 W, worst case 0.62 W.

## Input (VIN, 8-18 V)

The input power is estimated with:

* Module efficiency η ≈ 80 % at this light load. This is conservative; check the RECOM efficiency curve.
* Schottky D2 drop ≈ 0.35-0.45 V.

| VIN | P_in typical | I_in typical | P_in worst | I_in worst |
|---|---:|---:|---:|---:|
| 8 V | 0.34 W | 42 mA | 0.82 W | 103 mA |
| 12 V | 0.34 W | 28 mA | 0.80 W | 67 mA |
| 18 V | 0.33 W | 19 mA | 0.79 W | 44 mA |

**Total board power is ≈ 0.35 W typical and < 0.85 W worst case.**

Loss breakdown, worst case:

* Module: ≈ 0.16 W
* LDO: 0.09 W
* D2: 0.04 W
* TJA1051 (dominant): ≈ 0.2 W
* MCU: 0.13 W

Nothing needs a heatsink.

## Protection ratings

* **F1 PTC (hold 0.5 A):** normal current is ≤ 0.1 A, so the margin is 5×. It trips on a crowbar (reverse polarity) or a short.
* **D1 SMBJ18A:** V_RWM 18 V (maximum continuous input), V_BR ≥ 20 V, V_C 29.2 V @ 20.5 A.
* **D2 SS34:** 3 A / 40 V. Its reverse rating blocks a reversed 18 V input with margin.
* **C1:** 10 µF / 50 V X7R 1210.
* **C2:** 47 µF / 35 V electrolytic. It damps cable inductance ringing on hot-plug. It is **below** the module's 220 µF maximum capacitive load on the output side, and on the input side there is no limit.

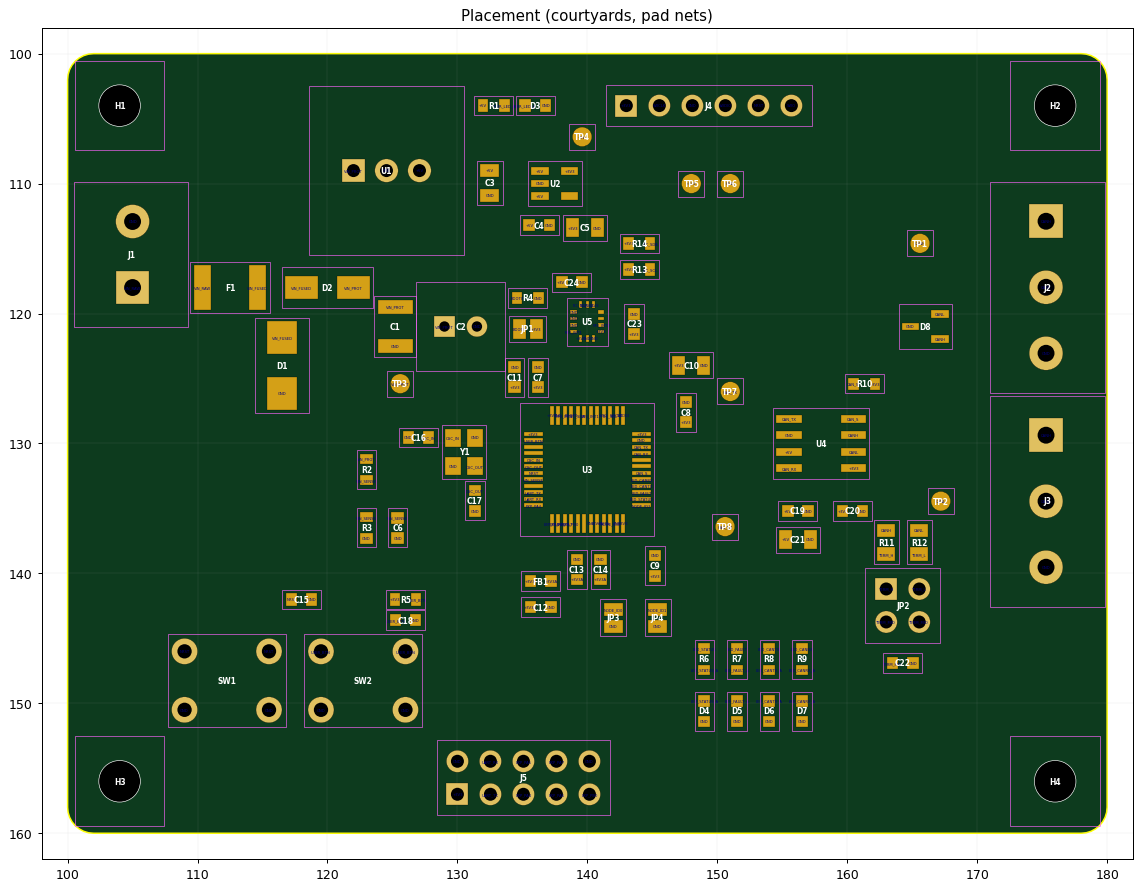
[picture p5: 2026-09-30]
docs/img/pcb_placement.png

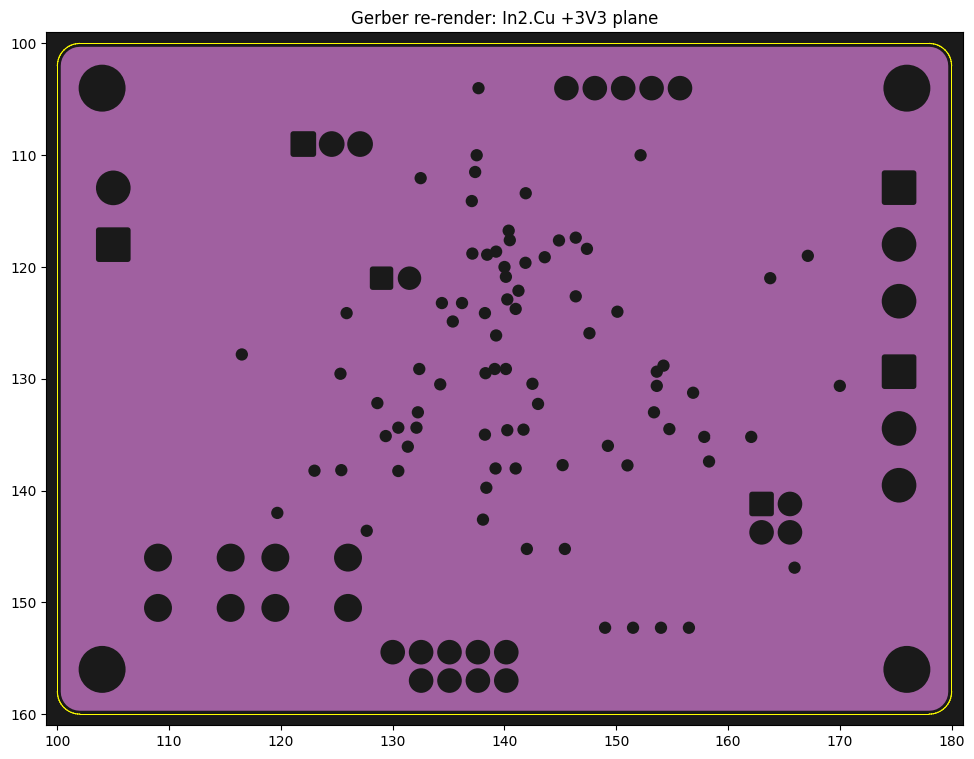
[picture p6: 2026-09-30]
docs/img/gerber_in2_3v3.png

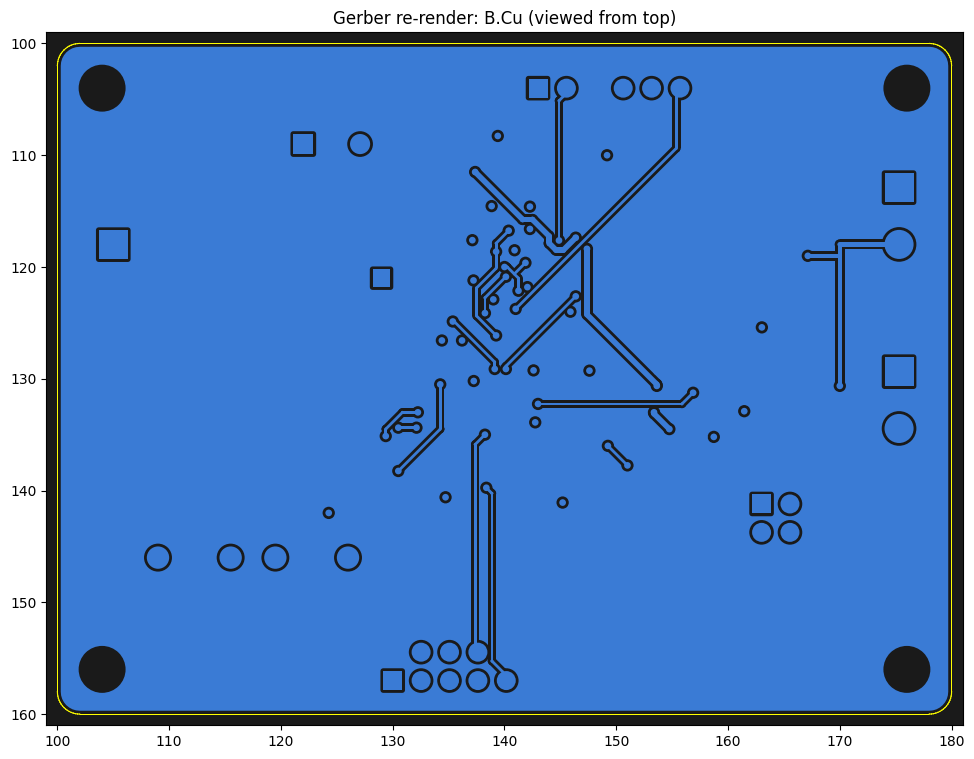
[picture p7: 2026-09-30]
docs/img/gerber_bottom.png

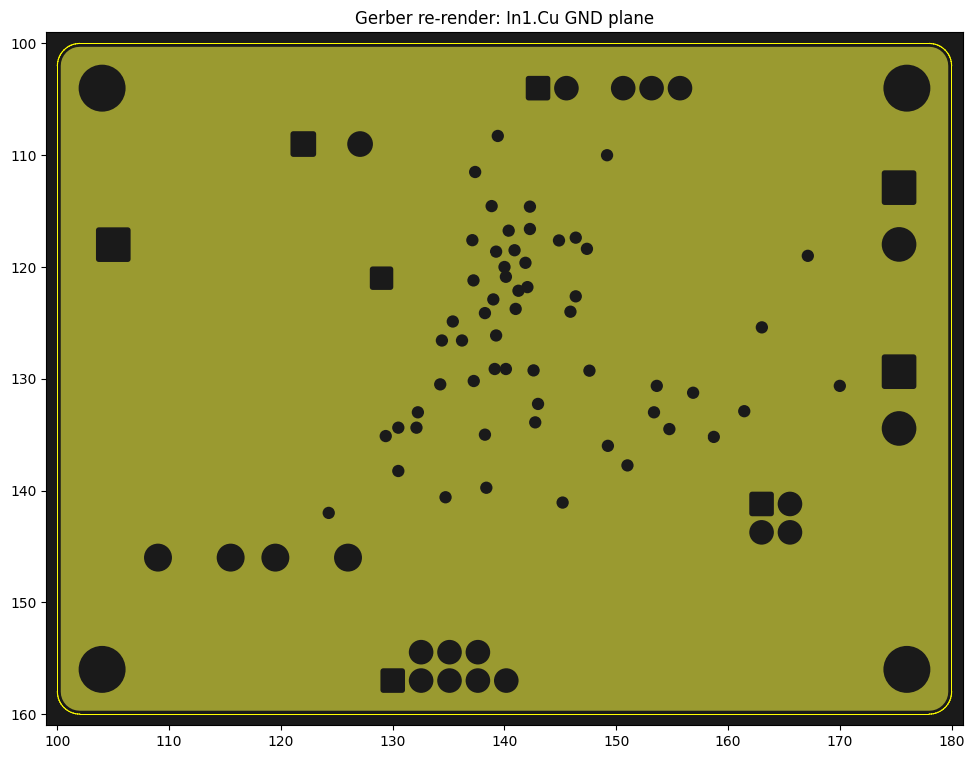
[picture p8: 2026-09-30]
docs/img/gerber_in1_gnd.png

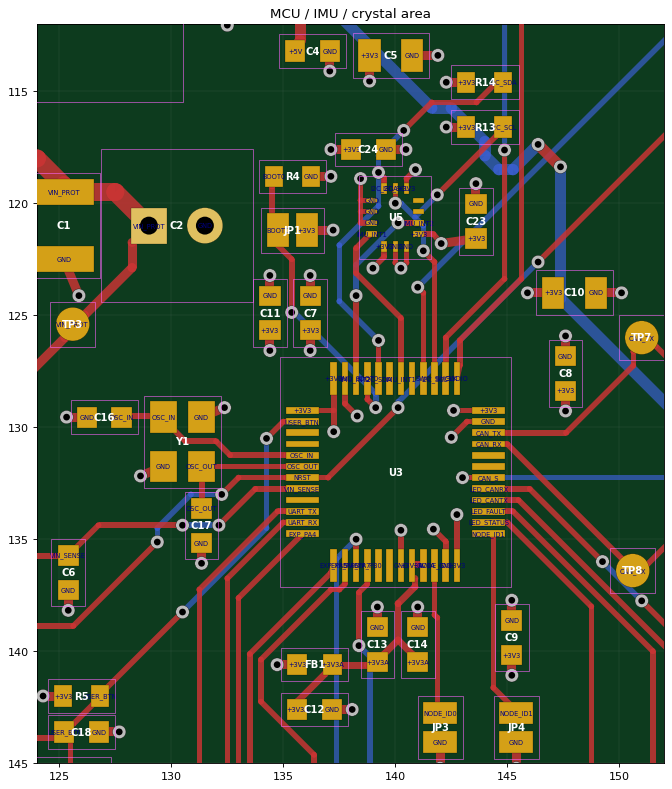
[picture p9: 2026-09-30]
docs/img/pcb_zoom_mcu.png

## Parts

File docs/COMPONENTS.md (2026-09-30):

# Component and footprint list

Generated from `hardware/gen/design.py` and `lib.py`. All footprints live in the project library `hardware/kicad/CAN_ECU.pretty` (self-contained project); the column *KiCad std* names the equivalent footprint in KiCad's official libraries, which you may swap in. Rows marked **VERIFY** must be checked against the manufacturer drawing of the exact part you buy before ordering PCBs.

## Components

| Ref | Value | Part / specification | Footprint | Function |
|---|---|---|---|---|
| C1 | 10uF 50V X7R | -  | C_1210_3225Metric | Input ceramic 10 uF 50 V X7R 1210 |
| C2 | 47uF 35V | 47 uF 35 V aluminium electrolytic, D6.3 mm, P2.5 mm, low-ESR  | CP_Radial_D6.3mm_P2.50mm | Input bulk / damping capacitor |
| C3 | 10uF 16V X5R | -  | C_0805_2012Metric | 5 V rail output capacitor 0805 |
| C4 | 1uF 16V X7R | -  | C_0603_1608Metric | LDO input capacitor |
| C5 | 10uF 10V X5R | -  | C_0805_2012Metric | LDO output capacitor |
| C6 | 100nF | -  | C_0603_1608Metric | Ceramic capacitor 100nF, 0603 |
| C7 | 100nF | -  | C_0603_1608Metric | VDD pin 48 decoupling |
| C8 | 100nF | -  | C_0603_1608Metric | VDD pin 36 decoupling |
| C9 | 100nF | -  | C_0603_1608Metric | VDD pin 24 decoupling |
| C10 | 4.7uF 10V X5R | -  | C_0805_2012Metric | VDD bulk |
| C11 | 100nF | -  | C_0603_1608Metric | VBAT decoupling |
| C12 | 1uF 16V X7R | -  | C_0603_1608Metric | VDDA bulk |
| C13 | 100nF | -  | C_0603_1608Metric | VDDA decoupling |
| C14 | 100nF | -  | C_0603_1608Metric | VREF+ decoupling |
| C15 | 100nF | -  | C_0603_1608Metric | NRST filter |
| C16 | 15pF C0G | -  | C_0603_1608Metric | HSE load cap (for CL = 12 pF crystal) |
| C17 | 15pF C0G | -  | C_0603_1608Metric | HSE load cap (for CL = 12 pF crystal) |
| C18 | 100nF | -  | C_0603_1608Metric | User button debounce |
| C19 | 100nF | -  | C_0603_1608Metric | Transceiver VCC decoupling |
| C20 | 100nF | -  | C_0603_1608Metric | Transceiver VIO decoupling |
| C21 | 4.7uF 16V X5R | -  | C_0805_2012Metric | Transceiver VCC bulk |
| C22 | 4.7nF 50V | -  | C_0603_1608Metric | Split termination common-mode capacitor |
| C23 | 100nF | -  | C_0603_1608Metric | IMU VDD decoupling |
| C24 | 100nF | -  | C_0603_1608Metric | IMU VDDIO decoupling |
| D1 | SMBJ18A | SMBJ18A (Littelfuse) | D_SMB | 600 W unidirectional TVS, VRWM 18 V, SMB |
| D2 | SS34 | SS34 (onsemi/various) | D_SMA | 3 A 40 V Schottky, reverse-polarity protection, SMA |
| D3 | GREEN PWR | 0603 green LED, Vf~2.0 V  | LED_0603_1608Metric | Power indicator (5 V rail) |
| D4 | GREEN STATUS | 0603 green LED  | LED_0603_1608Metric | STATUS indicator |
| D5 | RED FAULT | 0603 red LED  | LED_0603_1608Metric | FAULT indicator |
| D6 | YELLOW CAN-TX | 0603 yellow LED  | LED_0603_1608Metric | CAN-TX indicator |
| D7 | ORANGE CAN-RX | 0603 orange LED  | LED_0603_1608Metric | CAN-RX indicator |
| D8 | PESD1CAN | PESD1CAN,215 (Nexperia) | SOT-23 | CAN bus ESD protection, SOT-23 (verify pinout: 1,2 = bus lines, 3 = GND) |
| F1 | PTC 0.5A/30V | 1812 PTC, Ihold 0.5 A, Vmax >= 30 V (e.g. Bourns MF-MSMF series - select 30 V rated) (Bourns/Littelfuse) | Fuse_1812_4532Metric | Resettable PTC fuse, 1812 |
| FB1 | 600R@100MHz | BLM18AG601SN1D (or equiv. 0603 bead, >=200 mA) (Murata) | L_0603_1608Metric | VDDA filter bead |
| H1 | M3 | - (-) | MountingHole_3.2mm_M3 | M3 mounting hole (NPTH) |
| H2 | M3 | - (-) | MountingHole_3.2mm_M3 | M3 mounting hole (NPTH) |
| H3 | M3 | - (-) | MountingHole_3.2mm_M3 | M3 mounting hole (NPTH) |
| H4 | M3 | - (-) | MountingHole_3.2mm_M3 | M3 mounting hole (NPTH) |
| J1 | PWR_IN 8-18V | 1729128 (MKDS 1,5/ 2-5,08) or equivalent (Phoenix Contact) | TerminalBlock_1x02_P5.08mm_Horizontal | 2-pos 5.08 mm PCB screw terminal, power input (1 = +VIN, 2 = GND) |
| J2 | CAN | 1729131 (MKDS 1,5/ 3-5,08) or equivalent (Phoenix Contact) | TerminalBlock_1x03_P5.08mm_Horizontal | CAN bus connector (1 = CANH, 2 = CANL, 3 = GND); J2/J3 are paralleled for daisy-chain |
| J3 | CAN | 1729131 (MKDS 1,5/ 3-5,08) or equivalent (Phoenix Contact) | TerminalBlock_1x03_P5.08mm_Horizontal | CAN bus connector (1 = CANH, 2 = CANL, 3 = GND); J2/J3 are paralleled for daisy-chain |
| J4 | SWD | 1x6 2.54 mm pin header  | PinHeader_1x06_P2.54mm_Vertical | SWD: 1 VDD_TARGET, 2 SWCLK, 3 GND, 4 SWDIO, 5 NRST, 6 SWO (Nucleo CN4 order) |
| J5 | EXPANSION | 2x5 2.54 mm pin header  | PinHeader_2x05_P2.54mm_Vertical | Expansion / debug UART (USART2) |
| JP1 | BOOT0 | - (-) | SolderJumper-2_P1.3mm_Open_Pad1.0x1.5mm | Close to force ST system bootloader |
| JP2 | CAN_TERM | 2x2 2.54 mm header + 2 jumper shunts  | PinHeader_2x02_P2.54mm_Vertical | Termination enable: fit BOTH shunts (1-3 and 2-4) on end-of-bus nodes only |
| JP3 | NODE_ID0 | - (-) | SolderJumper-2_P1.3mm_Open_Pad1.0x1.5mm | Node-ID bit 0 (closed = 1) |
| JP4 | NODE_ID1 | - (-) | SolderJumper-2_P1.3mm_Open_Pad1.0x1.5mm | Node-ID bit 1 (closed = 1) |
| R1 | 1k5 | -  | R_0603_1608Metric | Resistor 1k5, 0603, 1%, thick film |
| R2 | 100k 1% | -  | R_0603_1608Metric | VIN divider top, 1% |
| R3 | 15k 1% | -  | R_0603_1608Metric | VIN divider bottom, 1% |
| R4 | 10k | -  | R_0603_1608Metric | BOOT0 pull-down (boot from Flash) |
| R5 | 10k | -  | R_0603_1608Metric | User button pull-up |
| R6 | 680R | -  | R_0603_1608Metric | Resistor 680R, 0603, 1%, thick film |
| R7 | 680R | -  | R_0603_1608Metric | Resistor 680R, 0603, 1%, thick film |
| R8 | 680R | -  | R_0603_1608Metric | Resistor 680R, 0603, 1%, thick film |
| R9 | 680R | -  | R_0603_1608Metric | Resistor 680R, 0603, 1%, thick film |
| R10 | 10k | -  | R_0603_1608Metric | Transceiver S pull-up: SILENT until firmware enables |
| R11 | 60R4 1% | -  | R_0805_2012Metric | Split termination 60.4R 0805 |
| R12 | 60R4 1% | -  | R_0805_2012Metric | Split termination 60.4R 0805 |
| R13 | 4k7 | -  | R_0603_1608Metric | I2C SCL pull-up |
| R14 | 4k7 | -  | R_0603_1608Metric | I2C SDA pull-up |
| SW1 | RESET | 6x6 mm THT tactile switch  | SW_PUSH_6mm | Reset push-button |
| SW2 | USER | 6x6 mm THT tactile switch  | SW_PUSH_6mm | User push-button |
| TP1 | CANH | - (-) | TestPoint_Pad_D1.5mm | Test pad CANH |
| TP2 | CANL | - (-) | TestPoint_Pad_D1.5mm | Test pad CANL |
| TP3 | VIN_PROT | - (-) | TestPoint_Pad_D1.5mm | Test pad VIN_PROT |
| TP4 | +5V | - (-) | TestPoint_Pad_D1.5mm | Test pad +5V |
| TP5 | +3V3 | - (-) | TestPoint_Pad_D1.5mm | Test pad +3V3 |
| TP6 | GND | - (-) | TestPoint_Pad_D1.5mm | Test pad GND |
| TP7 | CAN_TX | - (-) | TestPoint_Pad_D1.5mm | Test pad CAN_TX |
| TP8 | CAN_RX | - (-) | TestPoint_Pad_D1.5mm | Test pad CAN_RX |
| U1 | R-78E5.0-0.5 | R-78E5.0-0.5 (RECOM) | Converter_DCDC_RECOM_R-78E-0.5_THT | 5 V 0.5 A non-isolated switching regulator module, 7-28 V in, SIP-3 |
| U2 | AP2112K-3.3 | AP2112K-3.3TRG1 (Diodes Inc.) | SOT-23-5 | 3.3 V 600 mA LDO, SOT-23-5 |
| U3 | STM32G431CBT6 | STM32G431CBT6 (STMicroelectronics) | LQFP-48_7x7mm_P0.5mm | Cortex-M4F 170 MHz, 128 KB Flash, 32 KB RAM, FDCAN, LQFP48 |
| U4 | TJA1051T/3 | TJA1051T/3,118 (NXP) | SOIC-8_3.9x4.9mm_P1.27mm | High-speed CAN (FD) transceiver with VIO, SO8. Must be the /3 (VIO) variant! |
| U5 | LSM6DS3TR-C | LSM6DS3TR-C (STMicroelectronics) | LGA-14_3x2.5mm_P0.5mm_LayoutBorder3x4y | 6-axis IMU (accel + gyro), I2C addr 0x6A |
| Y1 | 8MHz CL12pF | 8.000 MHz, 3225 4-pad, +-20 ppm, CL = 12 pF (ESR <= 100R)  | Crystal_SMD_3225-4Pin_3.2x2.5mm | HSE crystal for accurate CAN bit timing |

## Footprints

| Project footprint | KiCad std equivalent | Type | Used by | Verification note |
|---|---|---|---|---|
| R_0603_1608Metric | Resistor_SMD:R_0603_1608Metric | smd | R1 R2 R3 R4 R5 R6 R7 R8 R9 R10 R13 R14 | Standard generic land pattern. |
| C_0603_1608Metric | Capacitor_SMD:C_0603_1608Metric | smd | C4 C6 C7 C8 C9 C11 C12 C13 C14 C15 C16 C17 C18 C19 C20 C22 C23 C24 | Standard generic land pattern. |
| L_0603_1608Metric | Inductor_SMD:L_0603_1608Metric | smd | FB1 | Standard generic land pattern. |
| C_0805_2012Metric | Capacitor_SMD:C_0805_2012Metric | smd | C3 C5 C10 C21 | Standard generic land pattern. |
| R_0805_2012Metric | Resistor_SMD:R_0805_2012Metric | smd | R11 R12 | Standard generic land pattern. |
| C_1210_3225Metric | Capacitor_SMD:C_1210_3225Metric | smd | C1 | Standard generic land pattern. |
| Fuse_1812_4532Metric | Fuse:Fuse_1812_4532Metric | smd | F1 | Generic 1812 PTC land pattern. |
| D_SMA | Diode_SMD:D_SMA | smd | D2 | Standard generic land pattern. |
| D_SMB | Diode_SMD:D_SMB | smd | D1 | Standard generic land pattern. |
| LED_0603_1608Metric | LED_SMD:LED_0603_1608Metric | smd | D3 D4 D5 D6 D7 | Standard generic land pattern. |
| SOIC-8_3.9x4.9mm_P1.27mm | Package_SO:SOIC-8_3.9x4.9mm_P1.27mm | smd | U4 | Standard JEDEC MS-012 land pattern. |
| LQFP-48_7x7mm_P0.5mm | Package_QFP:LQFP-48_7x7mm_P0.5mm | smd | U3 | Generated to IPC-7351-like dimensions (pads 1.475 x 0.3 at +-4.1625). Compare with KiCad Package_QFP:LQFP-48_7x7mm_P0.5mm. |
| SOT-23 | Package_TO_SOT_SMD:SOT-23 | smd | D8 | **VERIFY** PESD1CAN pinout (1 = CANH/line, 2 = CANL/line, 3 = common) - symmetric part, swapping 1/2 is harmless. |
| SOT-23-5 | Package_TO_SOT_SMD:SOT-23-5 | smd | U2 | AP2112K SOT-23-5 pinout checked (1 VIN, 2 GND, 3 EN, 4 NC, 5 VOUT). |
| LGA-14_3x2.5mm_P0.5mm_LayoutBorder3x4y | Package_LGA:LGA-14_3x2.5mm_P0.5mm_LayoutBorder3x4y | smd | U5 | **VERIFY** against ST LSM6DS3TR-C land-pattern recommendation (pads 0.5 x 0.25 mm). Pin-1 orientation is critical. |
| Crystal_SMD_3225-4Pin_3.2x2.5mm | Crystal:Crystal_SMD_3225-4Pin_3.2x2.5mm | smd | Y1 | Standard 3225 4-pad; confirm pad 1/3 = crystal, 2/4 = GND for the chosen part. |
| TerminalBlock_1x02_P5.08mm_Horizontal | TerminalBlock_Phoenix:TerminalBlock_Phoenix_MKDS-1,5-2-5.08_1x02_P5.08mm_Horizontal | through_hole | J1 | **VERIFY** hole size/pitch vs. the terminal block actually bought (Phoenix MKDS 1,5/2-5,08 style). |
| TerminalBlock_1x03_P5.08mm_Horizontal | TerminalBlock_Phoenix:TerminalBlock_Phoenix_MKDS-1,5-3-5.08_1x03_P5.08mm_Horizontal | through_hole | J2 J3 | **VERIFY** as above (3-pole). |
| PinHeader_1x06_P2.54mm_Vertical | Connector_PinHeader_2.54mm:PinHeader_1x06_P2.54mm_Vertical | through_hole | J4 | Standard generic land pattern. |
| PinHeader_2x05_P2.54mm_Vertical | Connector_PinHeader_2.54mm:PinHeader_2x05_P2.54mm_Vertical | through_hole | J5 | Standard generic land pattern. |
| PinHeader_2x02_P2.54mm_Vertical | Connector_PinHeader_2.54mm:PinHeader_2x02_P2.54mm_Vertical | through_hole | JP2 | Standard generic land pattern. |
| SW_PUSH_6mm | Button_Switch_THT:SW_PUSH_6mm | through_hole | SW1 SW2 | Standard generic land pattern. |
| Converter_DCDC_RECOM_R-78E-0.5_THT | Converter_DCDC:Converter_DCDC_RECOM_R-78E-0.5_THT | through_hole | U1 | **VERIFY** pin pitch (2.54 mm) and body side against the RECOM drawing; 6.5 mm keep-out reserved both sides. |
| CP_Radial_D6.3mm_P2.50mm | Capacitor_THT:CP_Radial_D6.3mm_P2.50mm | through_hole | C2 | Standard generic land pattern. |
| SolderJumper-2_P1.3mm_Open_Pad1.0x1.5mm | Jumper:SolderJumper-2_P1.3mm_Open_Pad1.0x1.5mm | smd | JP1 JP3 JP4 | Standard generic land pattern. |
| TestPoint_Pad_D1.5mm | TestPoint:TestPoint_Pad_D1.5mm | smd | TP1 TP2 TP3 TP4 TP5 TP6 TP7 TP8 | Standard generic land pattern. |
| MountingHole_3.2mm_M3 | MountingHole:MountingHole_3.2mm_M3 | exclude | H1 H2 H3 H4 | Standard generic land pattern. |

## BOM

See `hardware/fab/BOM.csv` (grouped, with rough cost estimates).

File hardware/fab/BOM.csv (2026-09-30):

Item | Qty | References | Value | Footprint (project lib) | Equivalent KiCad std footprint | MPN / specification | Manufacturer | Description | Mount | Est. unit USD | Est. ext. USD
1 | 1 | C1 | 10uF 50V X7R | C_1210_3225Metric | Capacitor_SMD:C_1210_3225Metric | generic 10uF 50V X7R, 1210 | any | Input ceramic 10 uF 50 V X7R 1210 | SMD | 0.35 | 0.35
2 | 1 | C2 | 47uF 35V | CP_Radial_D6.3mm_P2.50mm | Capacitor_THT:CP_Radial_D6.3mm_P2.50mm | 47 uF 35 V aluminium electrolytic, D6.3 mm, P2.5 mm, low-ESR | any | Input bulk / damping capacitor | THT | 0.20 | 0.20
3 | 1 | C3 | 10uF 16V X5R | C_0805_2012Metric | Capacitor_SMD:C_0805_2012Metric | generic 10uF 16V X5R, 0805 | any | 5 V rail output capacitor 0805 | SMD | 0.08 | 0.08
4 | 2 | C4 C12 | 1uF 16V X7R | C_0603_1608Metric | Capacitor_SMD:C_0603_1608Metric | generic 1uF 16V X7R, 0603 | any | LDO input capacitor; VDDA bulk | SMD | 0.03 | 0.06
5 | 1 | C5 | 10uF 10V X5R | C_0805_2012Metric | Capacitor_SMD:C_0805_2012Metric | generic 10uF 10V X5R, 0805 | any | LDO output capacitor | SMD | 0.08 | 0.08
6 | 13 | C6 C7 C8 C9 C11 C13 C14 C15 C18 C19 C20 C23 C24 | 100nF | C_0603_1608Metric | Capacitor_SMD:C_0603_1608Metric | generic 100nF, 0603 | any | Ceramic capacitor 100nF, 0603; IMU VDD decoupling; IMU VDDIO decoupling; NRST filter; Transceiver VCC decoupling; Transceiver VIO decoupling; User button debounce; VBAT decoupling; VDD pin 24 decoupling; VDD pin 36 decoupling; VDD pin 48 decoupling; VDDA decoupling; VREF+ decoupling | SMD | 0.02 | 0.26
7 | 1 | C10 | 4.7uF 10V X5R | C_0805_2012Metric | Capacitor_SMD:C_0805_2012Metric | generic 4.7uF 10V X5R, 0805 | any | VDD bulk | SMD | 0.06 | 0.06
8 | 2 | C16 C17 | 15pF C0G | C_0603_1608Metric | Capacitor_SMD:C_0603_1608Metric | generic 15pF C0G, 0603 | any | HSE load cap (for CL = 12 pF crystal) | SMD | 0.03 | 0.06
9 | 1 | C21 | 4.7uF 16V X5R | C_0805_2012Metric | Capacitor_SMD:C_0805_2012Metric | generic 4.7uF 16V X5R, 0805 | any | Transceiver VCC bulk | SMD | 0.06 | 0.06
10 | 1 | C22 | 4.7nF 50V | C_0603_1608Metric | Capacitor_SMD:C_0603_1608Metric | generic 4.7nF 50V, 0603 | any | Split termination common-mode capacitor | SMD | 0.03 | 0.03
11 | 1 | D1 | SMBJ18A | D_SMB | Diode_SMD:D_SMB | SMBJ18A | Littelfuse | 600 W unidirectional TVS, VRWM 18 V, SMB | SMD | 0.25 | 0.25
12 | 1 | D2 | SS34 | D_SMA | Diode_SMD:D_SMA | SS34 | onsemi/various | 3 A 40 V Schottky, reverse-polarity protection, SMA | SMD | 0.15 | 0.15
13 | 1 | D3 | GREEN PWR | LED_0603_1608Metric | LED_SMD:LED_0603_1608Metric | 0603 green LED, Vf~2.0 V | any | Power indicator (5 V rail) | SMD | 0.05 | 0.05
14 | 1 | D4 | GREEN STATUS | LED_0603_1608Metric | LED_SMD:LED_0603_1608Metric | 0603 green LED | any | STATUS indicator | SMD | 0.05 | 0.05
15 | 1 | D5 | RED FAULT | LED_0603_1608Metric | LED_SMD:LED_0603_1608Metric | 0603 red LED | any | FAULT indicator | SMD | 0.05 | 0.05
16 | 1 | D6 | YELLOW CAN-TX | LED_0603_1608Metric | LED_SMD:LED_0603_1608Metric | 0603 yellow LED | any | CAN-TX indicator | SMD | 0.05 | 0.05
17 | 1 | D7 | ORANGE CAN-RX | LED_0603_1608Metric | LED_SMD:LED_0603_1608Metric | 0603 orange LED | any | CAN-RX indicator | SMD | 0.05 | 0.05
18 | 1 | D8 | PESD1CAN | SOT-23 | Package_TO_SOT_SMD:SOT-23 | PESD1CAN,215 | Nexperia | CAN bus ESD protection, SOT-23 (verify pinout: 1,2 = bus lines, 3 = GND) | SMD | 0.25 | 0.25
19 | 1 | F1 | PTC 0.5A/30V | Fuse_1812_4532Metric | Fuse:Fuse_1812_4532Metric | 1812 PTC, Ihold 0.5 A, Vmax >= 30 V (e.g. Bourns MF-MSMF series - select 30 V rated) | Bourns/Littelfuse | Resettable PTC fuse, 1812 | SMD | 0.35 | 0.35
20 | 1 | FB1 | 600R@100MHz | L_0603_1608Metric | Inductor_SMD:L_0603_1608Metric | BLM18AG601SN1D (or equiv. 0603 bead, >=200 mA) | Murata | VDDA filter bead | SMD | 0.05 | 0.05
21 | 1 | J1 | PWR_IN 8-18V | TerminalBlock_1x02_P5.08mm_Horizontal | TerminalBlock_Phoenix:TerminalBlock_Phoenix_MKDS-1,5-2-5.08_1x02_P5.08mm_Horizontal | 1729128 (MKDS 1,5/ 2-5,08) or equivalent | Phoenix Contact | 2-pos 5.08 mm PCB screw terminal, power input (1 = +VIN, 2 = GND) | THT | 0.70 | 0.70
22 | 2 | J2 J3 | CAN | TerminalBlock_1x03_P5.08mm_Horizontal | TerminalBlock_Phoenix:TerminalBlock_Phoenix_MKDS-1,5-3-5.08_1x03_P5.08mm_Horizontal | 1729131 (MKDS 1,5/ 3-5,08) or equivalent | Phoenix Contact | CAN bus connector (1 = CANH, 2 = CANL, 3 = GND); J2/J3 are paralleled for daisy-chain | THT | 1.00 | 2.00
23 | 1 | J4 | SWD | PinHeader_1x06_P2.54mm_Vertical | Connector_PinHeader_2.54mm:PinHeader_1x06_P2.54mm_Vertical | 1x6 2.54 mm pin header | any | SWD: 1 VDD_TARGET, 2 SWCLK, 3 GND, 4 SWDIO, 5 NRST, 6 SWO (Nucleo CN4 order) | THT | 0.25 | 0.25
24 | 1 | J5 | EXPANSION | PinHeader_2x05_P2.54mm_Vertical | Connector_PinHeader_2.54mm:PinHeader_2x05_P2.54mm_Vertical | 2x5 2.54 mm pin header | any | Expansion / debug UART (USART2) | THT | 0.35 | 0.35
25 | 1 | JP2 | CAN_TERM | PinHeader_2x02_P2.54mm_Vertical | Connector_PinHeader_2.54mm:PinHeader_2x02_P2.54mm_Vertical | 2x2 2.54 mm header + 2 jumper shunts | any | Termination enable: fit BOTH shunts (1-3 and 2-4) on end-of-bus nodes only | THT | 0.30 | 0.30
26 | 1 | R1 | 1k5 | R_0603_1608Metric | Resistor_SMD:R_0603_1608Metric | generic 1k5, 0603 | any | Resistor 1k5, 0603, 1%, thick film | SMD | 0.01 | 0.01
27 | 1 | R2 | 100k 1% | R_0603_1608Metric | Resistor_SMD:R_0603_1608Metric | generic 100k 1%, 0603 | any | VIN divider top, 1% | SMD | 0.01 | 0.01
28 | 1 | R3 | 15k 1% | R_0603_1608Metric | Resistor_SMD:R_0603_1608Metric | generic 15k 1%, 0603 | any | VIN divider bottom, 1% | SMD | 0.01 | 0.01
29 | 3 | R4 R5 R10 | 10k | R_0603_1608Metric | Resistor_SMD:R_0603_1608Metric | generic 10k, 0603 | any | BOOT0 pull-down (boot from Flash); Transceiver S pull-up: SILENT until firmware enables; User button pull-up | SMD | 0.01 | 0.03
30 | 4 | R6 R7 R8 R9 | 680R | R_0603_1608Metric | Resistor_SMD:R_0603_1608Metric | generic 680R, 0603 | any | Resistor 680R, 0603, 1%, thick film | SMD | 0.01 | 0.04
31 | 2 | R11 R12 | 60R4 1% | R_0805_2012Metric | Resistor_SMD:R_0805_2012Metric | generic 60R4 1%, 0805 | any | Split termination 60.4R 0805 | SMD | 0.04 | 0.08
32 | 2 | R13 R14 | 4k7 | R_0603_1608Metric | Resistor_SMD:R_0603_1608Metric | generic 4k7, 0603 | any | I2C SCL pull-up; I2C SDA pull-up | SMD | 0.01 | 0.02
33 | 1 | SW1 | RESET | SW_PUSH_6mm | Button_Switch_THT:SW_PUSH_6mm | 6x6 mm THT tactile switch | any | Reset push-button | THT | 0.15 | 0.15
34 | 1 | SW2 | USER | SW_PUSH_6mm | Button_Switch_THT:SW_PUSH_6mm | 6x6 mm THT tactile switch | any | User push-button | THT | 0.15 | 0.15
35 | 1 | U1 | R-78E5.0-0.5 | Converter_DCDC_RECOM_R-78E-0.5_THT | Converter_DCDC:Converter_DCDC_RECOM_R-78E-0.5_THT | R-78E5.0-0.5 | RECOM | 5 V 0.5 A non-isolated switching regulator module, 7-28 V in, SIP-3 | THT | 3.60 | 3.60
36 | 1 | U2 | AP2112K-3.3 | SOT-23-5 | Package_TO_SOT_SMD:SOT-23-5 | AP2112K-3.3TRG1 | Diodes Inc. | 3.3 V 600 mA LDO, SOT-23-5 | SMD | 0.35 | 0.35
37 | 1 | U3 | STM32G431CBT6 | LQFP-48_7x7mm_P0.5mm | Package_QFP:LQFP-48_7x7mm_P0.5mm | STM32G431CBT6 | STMicroelectronics | Cortex-M4F 170 MHz, 128 KB Flash, 32 KB RAM, FDCAN, LQFP48 | SMD | 4.60 | 4.60
38 | 1 | U4 | TJA1051T/3 | SOIC-8_3.9x4.9mm_P1.27mm | Package_SO:SOIC-8_3.9x4.9mm_P1.27mm | TJA1051T/3,118 | NXP | High-speed CAN (FD) transceiver with VIO, SO8. Must be the /3 (VIO) variant! | SMD | 1.10 | 1.10
39 | 1 | U5 | LSM6DS3TR-C | LGA-14_3x2.5mm_P0.5mm_LayoutBorder3x4y | Package_LGA:LGA-14_3x2.5mm_P0.5mm_LayoutBorder3x4y | LSM6DS3TR-C | STMicroelectronics | 6-axis IMU (accel + gyro), I2C addr 0x6A | SMD | 2.40 | 2.40
40 | 1 | Y1 | 8MHz CL12pF | Crystal_SMD_3225-4Pin_3.2x2.5mm | Crystal:Crystal_SMD_3225-4Pin_3.2x2.5mm | 8.000 MHz, 3225 4-pad, +-20 ppm, CL = 12 pF (ESR <= 100R) | any | HSE crystal for accurate CAN bit timing | SMD | 0.40 | 0.40
 |  |  |  |  |  |  |  | Estimated component total per board (qty-10 pricing, ROUGH ESTIMATE - check distributor) |  |  | 19.09
 |  | JP1 JP3 JP4 | Solder jumpers |  |  | PCB feature - no part
 |  | TP1-TP8 | Test pads |  |  | PCB feature - no part
 |  | H1-H4 | M3 mounting holes |  |  | PCB feature - no part

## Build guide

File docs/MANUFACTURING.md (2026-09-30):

# Manufacturing notes

## PCB fabrication spec (give this to the PCB fab)

| Parameter | Value |
|---|---|
| Dimensions | 80.0 × 60.0 mm, rounded corners R2 |
| Layers | 4 (F.Cu, In1.Cu GND, In2.Cu +3V3, B.Cu) |
| Thickness | 1.6 mm FR-4, Tg ≥ 135 °C (standard) |
| Copper | 1 oz outer, 0.5 oz (or 1 oz) inner |
| Min track / space | 0.20 / 0.20 mm (design uses ≥ 0.25 mm tracks) |
| Min drill | 0.30 mm (vias 0.3 / 0.6 mm) |
| Solder mask | both sides, any colour; vias tented |
| Silkscreen | top only |
| Surface finish | ENIG recommended (flat pads for LGA-14 / LQFP); HASL lead-free acceptable |
| Impedance control | not required |

## Output files

### A. Preferred: re-plot from KiCad

In KiCad (7/8/9) with `hardware/kicad/CAN_ECU.kicad_pcb` open:

1. Press **B** to fill zones, then run DRC.
2. **File → Fabrication Outputs → Gerbers (.gbr)**.
   * Layers: F.Cu, In1.Cu, In2.Cu, B.Cu, F.Paste, F.Silkscreen, F.Mask, B.Mask, Edge.Cuts.
   * Check *Use Protel filename extensions* if your fab asks for it.
   * Click **Generate Drill Files…** (Excellon, PTH and NPTH in separate files, mm).
3. **File → Fabrication Outputs → Component Placement (.pos)** (CSV, mm, top side) and **BOM**.
4. Zip the folder and upload it to the fab.

### B. Pre-generated preview outputs (`hardware/fab/`)

Generated without KiCad by `hardware/gen/fab.py` from the same design data:

| File | Content |
|---|---|
| `gerber/CAN_ECU-F_Cu.gtl`, `-In1_Cu.g2`, `-In2_Cu.g3`, `-B_Cu.gbl` | Copper incl. poured planes (solid pad connections, no thermal reliefs, isolated islands not removed) |
| `gerber/CAN_ECU-F_Mask.gts`, `-B_Mask.gbs`, `-F_Paste.gtp`, `-F_Silkscreen.gto`, `-Edge_Cuts.gm1` | Mask (0.05 mm expansion), paste, legend, outline |
| `drill/CAN_ECU-PTH.drl`, `drill/CAN_ECU-NPTH.drl` | Excellon, metric, Y-axis matches the Gerbers |
| `BOM.csv` | Grouped BOM with rough cost estimates |
| `CPL_top.csv` | Pick-and-place, origin = bottom-left board corner, Y up, rotation CCW |

The Gerbers were re-rendered by an independent parser (`docs/img/gerber_*.png`) for a visual check. **They are review previews:** use them to inspect the design in any Gerber viewer. **Order from the KiCad re-plot (A)**, which also adds thermal reliefs and removes copper islands.

## Assembly notes

* **U5 (LSM6DS3TR-C, LGA-14, 2.5 × 3 mm, no leads):** needs stencil + reflow or hot air. Pin 1 marking is on the package top. The board has a silk dot at pin 1. Keep reflow profile peak ≤ 260 °C, as specified by ST for the LGA.
* **U3 (LQFP48 0.5 mm):** hand-solderable with drag soldering + flux. Check for bridges under magnification.
* **THT parts (hand-soldered after reflow):** J1-J5, JP2, SW1, SW2, C2, U1 (R-78E). Mount the R-78E upright with the label side as shown on the silk.
* **Rotation offsets:** pick-and-place rotations follow KiCad's convention. Many assembly services apply their own per-footprint offsets (especially for SOT-23, SOIC and diodes), so review the assembler's placement preview.
* **Shunts:** JP2 needs **2 jumper shunts** (2.54 mm) on end-of-bus boards. JP1/JP3/JP4 are solder jumpers: close them with a solder blob.

## Cost estimate (rough)

| Item | Estimate |
|---|---|
| Components per board (qty-10 distributor pricing, see `BOM.csv`) | ≈ USD 19 |
| 4-layer PCB 80 × 60 mm, qty 5 at a low-cost prototype fab | ≈ USD 2-8 per board + shipping |
| Stencil (optional, recommended for the LGA) | ≈ USD 8-15 |

These are **estimates only** (2025/2026 price levels). Check current distributor and fab prices.

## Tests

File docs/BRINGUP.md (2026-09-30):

# Bring-up procedure and two-board CAN test

Equipment needed:

* Lab supply with current limit
* Multimeter
* ST-LINK
* 3.3 V USB-UART adapter
* Optional: oscilloscope, USB-CAN adapter (CANable/PCAN/Kvaser/SocketCAN)

## 1. Before power (bare / assembled board)

1. Visual inspection under magnification: LQFP and LGA bridges, orientation of U1 (R-78E), D1, D2, D3-D7, U3 pin 1, U4 pin 1, U5 pin 1, C2 polarity.
2. Resistance to GND. None may be a short. Capacitor charging is normal.

   | Node | Test point | Expected |
   |---|---|---|
   | VIN_PROT | TP3 | > 10 kΩ |
   | +5V | TP4 | > 1 kΩ |
   | +3V3 | TP5 | > 500 Ω |
   | CANH–CANL | J2 pin 1–2 | ≈ 120 Ω with JP2 shunts fitted, open (> 10 kΩ) without |

## 2. First power-up (no MCU firmware yet)

1. Set the supply to **12 V, current limit 150 mA**, and connect J1 (+ = pin 1 marked "+").
2. Expect about 5-25 mA and the PWR LED on.
   * > 60 mA with blank firmware means something is wrong. Switch off and investigate.
3. Measure the rails:

   | Test point | Rail | Expected |
   |---|---|---|
   | TP3 | VIN_PROT | VIN − 0.3…0.5 V |
   | TP4 | +5V | 4.9-5.1 V |
   | TP5 | +3V3 | 3.25-3.35 V |
   | C12/C13 | +3V3A (VDDA) | ≈ 3.3 V |

4. Reverse-polarity test (optional, do it once): apply −12 V with the limit at 150 mA. The supply goes into current limit and the board must survive. Restore the correct polarity; the PTC recovers after cooling.
5. Sweep VIN 8 → 18 V. +5 V must stay in regulation.

## 3. Programming

See `docs/FIRMWARE.md` → Programming.

1. Connect the ST-LINK to J4 and read the device ID with STM32CubeProgrammer (should be 0x468, STM32G431).
2. Flash `can_ecu.hex`.
3. With the UART connected at 115200 8N1 you should see:

```
STM32 CAN ECU fw 1.0  node 0  reset cause 2  clock HSE 8 MHz  IMU WHO_AM_I 0x6A
node 0 DEGRADED faults act=0x0008 lat=0x0008 | VIN 12031 mV MCU 31 C | acc 12 -35 998 mg | ...
```

A **single** board reports `CAN_PASSIVE` (0x0008) and state DEGRADED. This is correct: nobody acknowledges its frames. You will see TEC 128 and the CAN-TX LED flickering at retry rate.

Check on the single board:

* Tilt the board. `acc` must follow gravity (±1000 mg on the axis pointing up/down).
* `clock HSE 8 MHz` is printed. If it prints `HSI16 FALLBACK`, check the crystal and C16/C17.
* The VIN reading matches the supply within ±3 %.
* The USER button prints `[btn] IDENTIFY sent`.
* Optional: probe the crystal with a 10× probe on OSC_OUT (C17), about 8 MHz.

## 4. Two-board CAN test (the main acceptance test)

**Setup:**

* **Board A:** JP3 and JP4 open → **node 0**.
* **Board B:** JP3 closed with a solder blob → **node 1**. Node IDs must differ; a duplicate ID gives fault `ID_CONFLICT`.
* **Termination:** fit **both** JP2 shunts (1-3 and 2-4) on **both** boards, since each is one end of a 2-node bus.

**Wiring:**

| Board A (J2 or J3) | Board B (J2 or J3) |
|---|---|
| 1 CANH | 1 CANH |
| 2 CANL | 2 CANL |
| 3 GND | 3 GND |

Use a twisted pair for CANH/CANL, plus the GND wire, up to a few metres. Each board can have its own supply, but the GND wire in the CAN cable is required.

**Check the termination with power OFF:** measure between CANH and CANL on either connector. It must read **≈ 60 Ω** (two 120 Ω in parallel).

**Procedure:**

1. **Power both boards.** Within about 1 s both STATUS LEDs change from fast blink to a **1 Hz short flash (RUN)**. Both CAN-TX and CAN-RX LEDs flicker, and the FAULT LEDs go off. You may see a slow FAULT flash if a latched `CAN_PASSIVE` from start-up is still stored; a long button press clears it.
2. **UART of board A:**
   * `[can] peer node 1 online (fw 1.0)` appears.
   * The status line shows `RUN faults act=0x0000`, `peers 0x2`, `TEC 0 REC 0`.
   * The `peer 1 ... acc` line shows board B's accelerometer. Tilt board B and watch the values change on board A.
3. **Identify:** press USER on board A. Board B's STATUS LED blinks at 10 Hz for 3 s and its UART prints `[cmd] IDENTIFY from node 0`. Repeat in the other direction.
4. **Timeout test:** unplug the CAN cable.
   * Within 300 ms both boards print `peer ... TIMEOUT` and go to DEGRADED (2 Hz blink).
   * Each has fault `PEER_TIMEOUT`, and also `CAN_PASSIVE`, since there is now no acknowledge.
   * Replug: both return to RUN automatically.
5. **Bus-off test:** short CANH to CANL briefly (< 1 s) while running.
   * The TEC rises and the node may go bus-off (FAULT state, STATUS off, FAULT LED on).
   * After the short is removed it recovers automatically. `busoff_count` in DIAG increments.
6. **With a USB-CAN adapter** (500 kbit/s), for example with Linux SocketCAN:

   ```bash
   sudo ip link set can0 type can bitrate 500000 && sudo ip link set can0 up
   candump can0                               # raw frames 0x100-0x104, 0x110-0x114
   python3 tools/can_monitor.py -i socketcan -c can0   # decoded view, CRC/counter check
   python3 tools/can_monitor.py -i socketcan -c can0 --identify 255
   ```

   Expected:
   * About 121 frames/s per node.
   * Zero CRC errors, zero lost/repeated counters.
   * ACCEL Z ≈ +1000 mg on a flat board.
   * VIN ≈ supply voltage.

   The `.dbc` in `tools/` loads into SavvyCAN, BusMaster, Vector or PCAN-Explorer.
7. **Scope (optional):**
   * CANH idles at 2.5 V and goes to ~3.5 V when dominant; CANL idles at 2.5 V and goes to ~1.5 V.
   * Differential dominant voltage ≈ 2 V.
   * Bit time 2.0 µs.
   * Clean edges, no ringing > 10 % with correct termination.

## 5. Troubleshooting

| Symptom | Likely cause / check |
|---|---|
| No PWR LED | polarity; F1 tripped (let it cool); U1 orientation; VIN < 7 V |
| +5 V ok, no +3V3 | U2 EN (pin 3) must be at 5 V; U2 orientation; short on +3V3 |
| ST-LINK cannot connect | NRST connected? try "connect under reset"; BOOT0 jumper open; VDD at J4.1 = 3.3 V; SWDIO/SWCLK swapped? |
| `HSI16 FALLBACK` | crystal not oscillating: solder joints, wrong CL/caps, crystal 3225 pad mapping (pads 1/3 must be the crystal) |
| `IMU WHO_AM_I 0x00`, fault IMU_COMM | LGA soldering (most common), pull-ups R13/R14, SA0 must be GND (addr 0x6A) |
| Alone on bus: DEGRADED, CAN_PASSIVE | **normal** - needs a second node to acknowledge |
| Two boards, no communication | same node ID? (ID_CONFLICT); CANH/CANL swapped between boards; GND wire missing; termination not ≈ 60 Ω; transceiver S pin stuck high (PA8) |
| CRC/E2E errors | mismatched firmware versions; noisy bus - check termination and GND |
| Frequent watchdog resets (reset cause 4) | a blocking call - check UART connection (20 ms timeout), I2C bus lock-up |
| Board resets when CAN bus shorted to 12 V | not protected: TJA1051 bus pins are rated −58…+58 V, but check wiring - never connect VIN to CAN lines |

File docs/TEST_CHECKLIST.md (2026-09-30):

# Test checklist (tick per board)

Board S/N: ______  Node ID: ___  Date: ______  Tester: ______

## Assembly / visual
- [ ] Correct orientation: U1, U2, U3 (pin 1), U4 (pin 1), U5 (pin 1), D1, D2, D3-D8, C2 (+)
- [ ] No solder bridges on U3 (LQFP48) and U4; U5 (LGA) centred, no visible bridging
- [ ] JP1 open, JP3/JP4 set to the planned node ID, JP2 shunts only on end-of-bus boards

## Power (supply current limit 150 mA)
- [ ] No short: TP3/TP4/TP5 to GND resistance OK
- [ ] 12 V input current (blank MCU) ______ mA (expect 5-25 mA)
- [ ] TP4 +5V = ______ V (4.9-5.1)   - [ ] TP5 +3V3 = ______ V (3.25-3.35)
- [ ] VDDA (C12) ≈ 3.3 V
- [ ] 8 V and 18 V input: +5 V and +3V3 in tolerance
- [ ] Reverse polarity 12 V (limited): board survives, PTC recovers (sample test)

## Programming / MCU
- [ ] ST-LINK connects, device ID 0x468
- [ ] Firmware flashed and verified
- [ ] UART banner shows `clock HSE 8 MHz`
- [ ] Reset button restarts (banner, reset cause 2)
- [ ] BOOT0 jumper closed → ROM bootloader answers (optional)

## Peripherals
- [ ] IMU WHO_AM_I = 0x6A, accel magnitude ≈ 1000 mg at rest, axes follow tilt
- [ ] Gyro ≈ 0 at rest (|x|,|y|,|z| < 3 dps), reacts to rotation
- [ ] VIN reading within ±3 % of the supply
- [ ] All LEDs work: PWR, STATUS, FAULT, CAN-TX, CAN-RX
- [ ] USER short press → IDENTIFY sent; long press → faults cleared

## CAN (with a second board or USB-CAN adapter)
- [ ] CANH-CANL resistance (power off): ______ Ω (≈60 Ω on a correctly terminated bus)
- [ ] Peer detected, both nodes RUN, TEC = REC = 0
- [ ] Frames 0x1n0-0x1n4 visible at the expected rates (tools/can_monitor.py), 0 CRC errors, 0 lost frames over 60 s
- [ ] IDENTIFY command works in both directions
- [ ] Cable unplugged → PEER_TIMEOUT within 300 ms, automatic recovery on replug
- [ ] Short CANH-CANL → bus-off → automatic recovery, busoff_count incremented
- [ ] Watchdog: (debug build) halt loop via debugger with IWDG unfrozen → reset cause 4, WDG_RESET latched

Result: PASS / FAIL   Notes: ____________________________________________

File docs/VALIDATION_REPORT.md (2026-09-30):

# Validation report

KiCad itself was **not available** in the environment where this design was generated, so KiCad's own ERC/DRC could not be run. Instead the checks below were implemented independently and run on the generated data and files. **Run KiCad ERC and DRC yourself before ordering** (see docs/MANUFACTURING.md).

## 1. PCB design-rule and connectivity check (hardware/gen/checks.py)

Rules: copper clearance 0.20 mm, copper-edge 0.30 mm, hole-hole 0.25 mm, min track 0.20 mm, no via-in-pad, courtyard overlap, full net connectivity including the In1 (GND) / In2 (+3V3) planes (raster flood-fill with 0.25 mm antipads).

```
DRC violations      : 0
Courtyard issues    : []
Unconnected nets    : 0
Netlist issues      : []
Plane copper islands: {'In1.Cu': 1, 'In2.Cu': 3} | members per island: {'In1.Cu': {1: 58}, 'In2.Cu': {1: 25}}
Tracks: 384 Vias: 103
```

Note: In2.Cu shows small isolated copper islands with no +3V3 connection; KiCad removes these automatically when zones are filled (default island removal).

## 2. Generated-file check (hardware/gen/validate_files.py)

Re-parses the KiCad files: S-expression syntax of every file, schematic connectivity rebuilt from wires / labels / pin positions and compared net-by-net with the design netlist, ERC subset (unconnected pins, undriven power inputs, conflicting outputs/labels, single-pin nets), PCB pad nets vs. schematic, closed board outline, silkscreen vs. pads / edge / other text.

```
  sch_symbols80
  sch_nets         46
  sch_wires        216
  sch_labels       216
  sch_noconnect    12
  pcb_footprints   77
  pcb_segments     384
  pcb_vias         103
  pcb_zones        4
  pcb_nets         46
  silk_texts       96
ERRORS: 0
```

## 3. Firmware host tests (firmware/tests)

```
make: Entering directory '/home/claude/stm32-can-ecu/firmware/tests'
cc -std=c11 -Wall -Wextra -Wpedantic -Werror -O1 -g -DUNIT_TEST -I../Core/Inc -fsanitize=address,undefined -o test_runner test_main.c ../Core/Src/can_protocol.c ../Core/Src/diagnostics.c ../Core/Src/imu.c
./test_runner
VECTOR 0x110 01 01 00 00 01 10 03 3A
VECTOR 0x101 0C 00 DD FF E6 03 17 7E
60 checks passed, 0 failed
  stub-compiled ../Core/Src/app.c
  stub-compiled ../Core/Src/board.c
  stub-compiled ../Core/Src/can.c
  stub-compiled ../Core/Src/can_protocol.c
  stub-compiled ../Core/Src/debug.c
  stub-compiled ../Core/Src/diagnostics.c
  stub-compiled ../Core/Src/imu.c
  stub-compiled ../Core/Src/main.c
  stub-compiled ../Core/Src/stm32g4xx_hal_msp.c
  stub-compiled ../Core/Src/stm32g4xx_it.c
make: Leaving directory '/home/claude/stm32-can-ecu/firmware/tests'
```

## 4. PC tools self-test (tools/test_tools.py)

```
tools self-test: 178 checks passed
```

## What could NOT be verified here

* KiCad ERC/DRC and zone filling (file format written for KiCad 7; opens in KiCad 7/8/9).
* A real `arm-none-eabi-gcc` build against the ST HAL (only a stub-HAL compile check was possible). Build it with the CMake project or STM32CubeIDE - see docs/FIRMWARE.md.
* Signal integrity / EMC, thermal behaviour, crystal start-up margin - require hardware measurement.
* Footprints marked VERIFY in docs/COMPONENTS.md against the exact purchased parts.

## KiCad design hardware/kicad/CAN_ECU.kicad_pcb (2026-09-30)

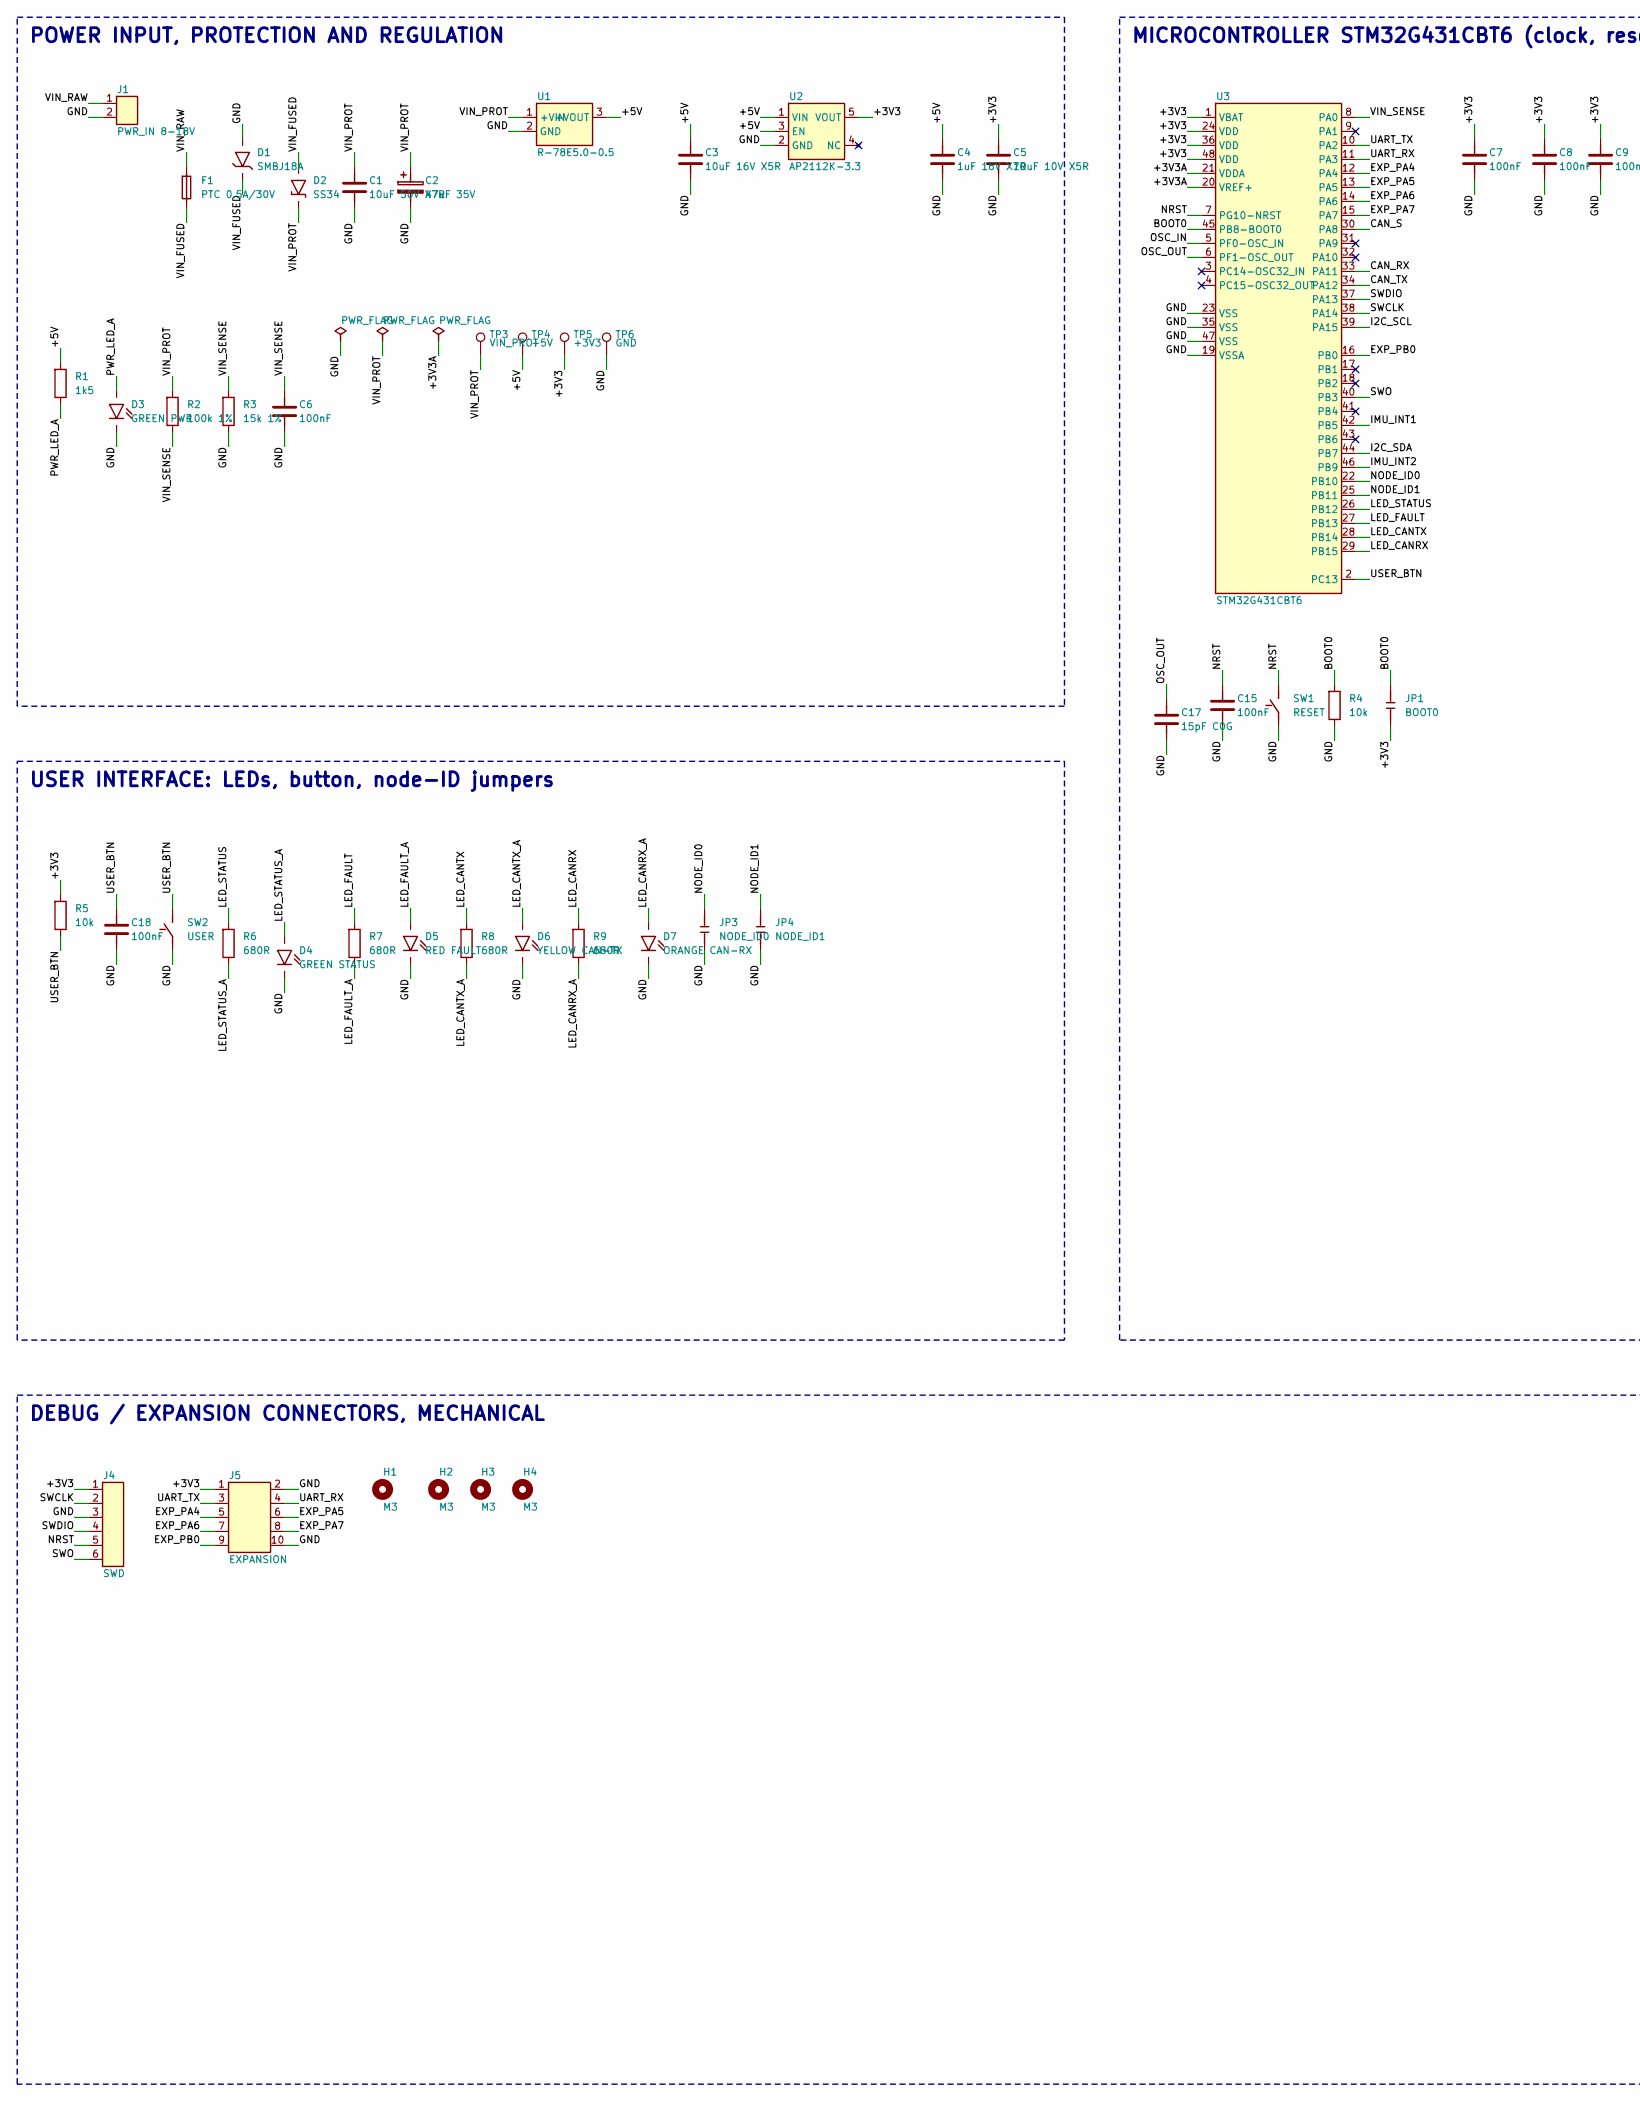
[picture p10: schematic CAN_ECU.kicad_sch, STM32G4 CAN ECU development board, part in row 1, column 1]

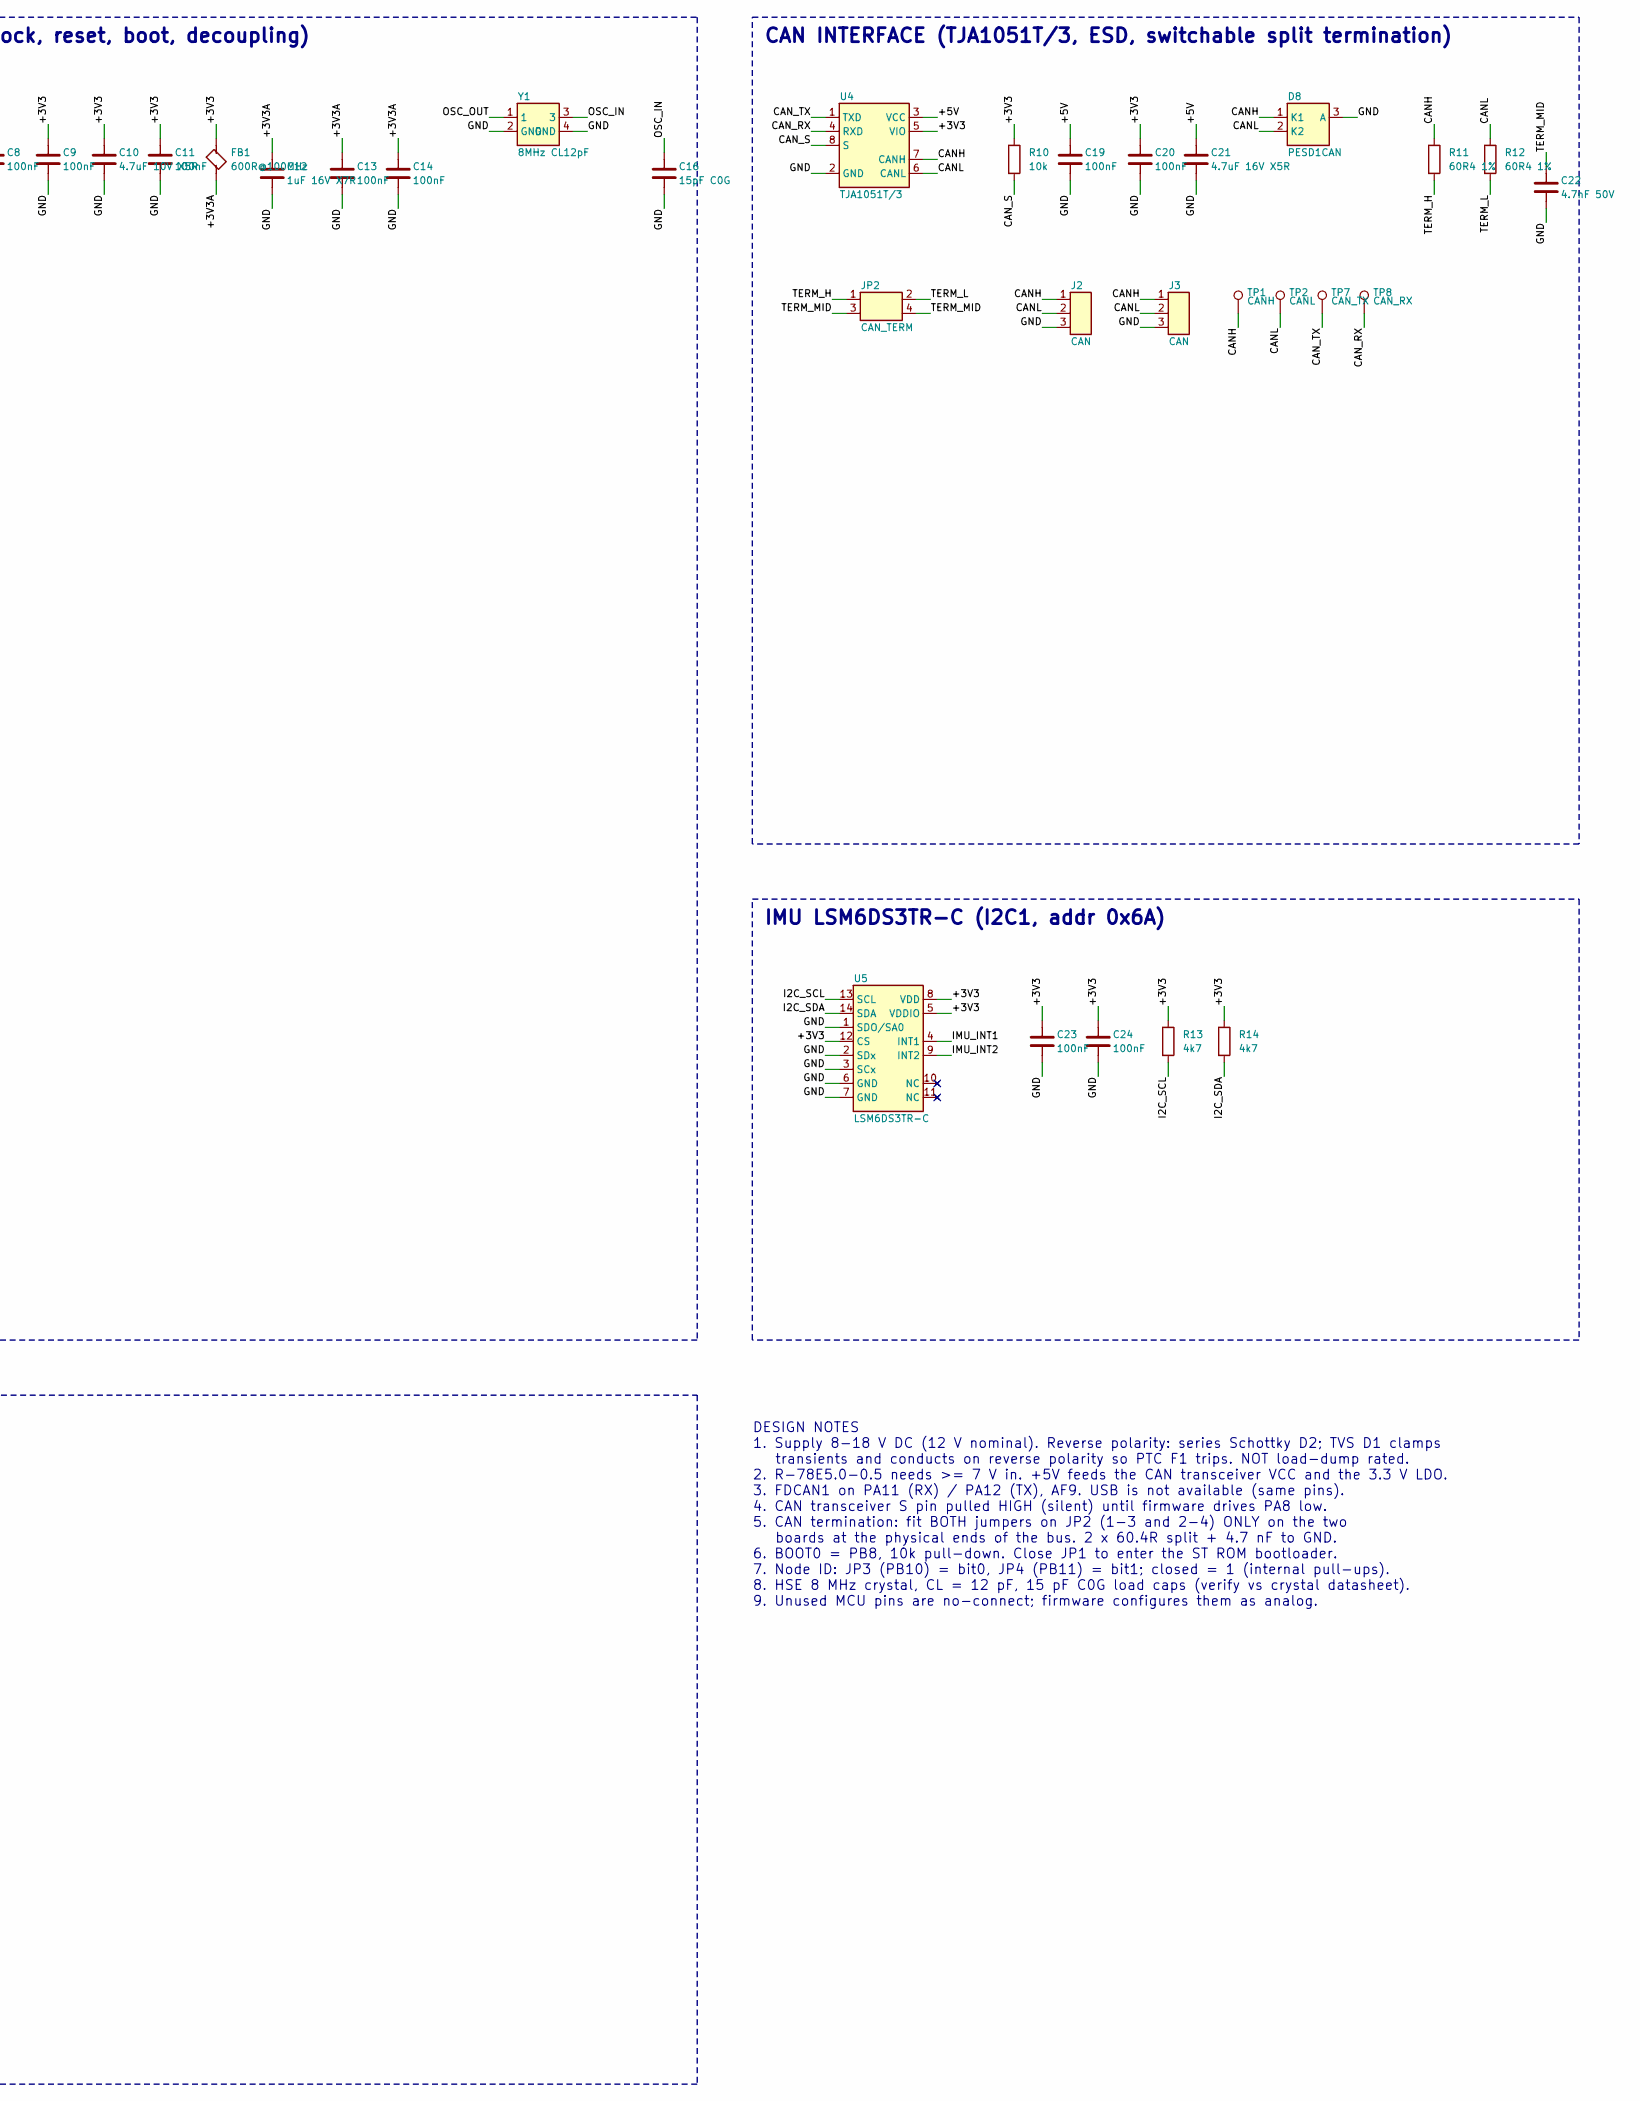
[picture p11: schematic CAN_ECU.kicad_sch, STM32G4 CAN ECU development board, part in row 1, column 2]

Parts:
C1: 10uF 50V X7R; C_1210_3225Metric
C2: 47uF 35V; CP_Radial_D6.3mm_P2.50mm; MPN 47 uF 35 V aluminium electrolytic, D6.3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
C3: 10uF 16V X5R; C_0805_2012Metric
C4, C12: 1uF 16V X7R; C_0603_1608Metric
C5: 10uF 10V X5R; C_0805_2012Metric
C6, C7, C8, C9, C11, C13, C14, C15, C18, C19, C20, C23, C24: 100nF; C_0603_1608Metric
C10: 4.7uF 10V X5R; C_0805_2012Metric
C16, C17: 15pF C0G; C_0603_1608Metric
C21: 4.7uF 16V X5R; C_0805_2012Metric
C22: 4.7nF 50V; C_0603_1608Metric
D1: SMBJ18A; D_SMB; MPN SMBJ18A
D2: SS34; D_SMA; MPN SS34
D3: GREEN PWR; LED_0603_1608Metric; MPN 0603 green LED, Vf~2.0 V
D4: GREEN STATUS; LED_0603_1608Metric; MPN 0603 green LED
D5: RED FAULT; LED_0603_1608Metric; MPN 0603 red LED
D6: YELLOW CAN-TX; LED_0603_1608Metric; MPN 0603 yellow LED
D7: ORANGE CAN-RX; LED_0603_1608Metric; MPN 0603 orange LED
D8: PESD1CAN; SOT-23; MPN PESD1CAN,215
F1: PTC 0.5A/30V; Fuse_1812_4532Metric; MPN 1812 PTC, Ihold 0.5 A, Vmax >= 30 V (e.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
FB1: 600R@100MHz; L_0603_1608Metric; MPN BLM18AG601SN1D (or equiv. 0603 bead, >=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
H1, H2, H3, H4: M3; MountingHole_3.2mm_M3
J1: PWR_IN 8-18V; TerminalBlock_1x02_P5.08mm_Horizontal; MPN 1729128 (MKDS 1,5/ 2-5,08) or equivalent
J2, J3: CAN; TerminalBlock_1x03_P5.08mm_Horizontal; MPN 1729131 (MKDS 1,5/ 3-5,08) or equivalent
J4: SWD; PinHeader_1x06_P2.54mm_Vertical; MPN 1x6 2.54 mm pin header
J5: EXPANSION; PinHeader_2x05_P2.54mm_Vertical; MPN 2x5 2.54 mm pin header
JP1: BOOT0; SolderJumper-2_P1.3mm_Open_Pad1.0x1.5mm
JP2: CAN_TERM; PinHeader_2x02_P2.54mm_Vertical; MPN 2x2 2.54 mm header + 2 jumper shunts
JP3: NODE_ID0; SolderJumper-2_P1.3mm_Open_Pad1.0x1.5mm
JP4: NODE_ID1; SolderJumper-2_P1.3mm_Open_Pad1.0x1.5mm
R1: 1k5; R_0603_1608Metric
R2: 100k 1%; R_0603_1608Metric
R3: 15k 1%; R_0603_1608Metric
R4, R5, R10: 10k; R_0603_1608Metric
R6, R7, R8, R9: 680R; R_0603_1608Metric
R11, R12: 60R4 1%; R_0805_2012Metric
R13, R14: 4k7; R_0603_1608Metric
SW1: RESET; SW_PUSH_6mm; MPN 6x6 mm THT tactile switch
SW2: USER; SW_PUSH_6mm; MPN 6x6 mm THT tactile switch
TP1: CANH; TestPoint_Pad_D1.5mm
TP2: CANL; TestPoint_Pad_D1.5mm
TP3: VIN_PROT; TestPoint_Pad_D1.5mm
TP4: +5V; TestPoint_Pad_D1.5mm
TP5: +3V3; TestPoint_Pad_D1.5mm
TP6: GND; TestPoint_Pad_D1.5mm
TP7: CAN_TX; TestPoint_Pad_D1.5mm
TP8: CAN_RX; TestPoint_Pad_D1.5mm
U1: R-78E5.0-0.5; Converter_DCDC_RECOM_R-78E-0.5_THT; MPN R-78E5.0-0.5
U2: AP2112K-3.3; SOT-23-5; MPN AP2112K-3.3TRG1
U3: STM32G431CBT6; LQFP-48_7x7mm_P0.5mm; MPN STM32G431CBT6
U4: TJA1051T/3; SOIC-8_3.9x4.9mm_P1.27mm; MPN TJA1051T/3,118
U5: LSM6DS3TR-C; LGA-14_3x2.5mm_P0.5mm_LayoutBorder3x4y; MPN LSM6DS3TR-C
Y1: 8MHz CL12pF; Crystal_SMD_3225-4Pin_3.2x2.5mm; MPN 8.000 MHz, 3225 4-pad, +-20 ppm, CL = 1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

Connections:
+3V3: C5.1, C7.1, C8.1, C9.1, C10.1, C11.1, C20.1, C23.1, C24.1, FB1.1, J4.1, J5.1, JP1.2, R5.1, R10.1, R13.1, R14.1, TP5.1, U2.5 (VOUT), U3.1 (VBAT), U3.24 (VDD), U3.36 (VDD), U3.48 (VDD), U4.5 (VIO), U5.5 (VDDIO), U5.8 (VDD), U5.12 (CS)
+3V3A: C12.1, C13.1, C14.1, FB1.2, U3.20 (VREF+), U3.21 (VDDA)
+5V: C3.1, C4.1, C19.1, C21.1, R1.1, TP4.1, U1.3 (+VOUT), U2.1 (VIN), U2.3 (EN), U4.3 (VCC)
BOOT0: JP1.1, R4.1, U3.45 (PB8-BOOT0)
CANH: D8.1 (K1), J2.1, J3.1, R11.1, TP1.1, U4.7 (CANH)
CANL: D8.2 (K2), J2.2, J3.2, R12.1, TP2.1, U4.6 (CANL)
CAN_RX: TP8.1, U3.33 (PA11), U4.4 (RXD)
CAN_S: R10.2, U3.30 (PA8), U4.8 (S)
CAN_TX: TP7.1, U3.34 (PA12), U4.1 (TXD)
EXP_PA4: J5.5, U3.12 (PA4)
EXP_PA5: J5.6, U3.13 (PA5)
EXP_PA6: J5.7, U3.14 (PA6)
EXP_PA7: J5.8, U3.15 (PA7)
EXP_PB0: J5.9, U3.16 (PB0)
GND: C1.2, C2.2, C3.2, C4.2, C5.2, C6.2, C7.2, C8.2, C9.2, C10.2, C11.2, C12.2, C13.2, C14.2, C15.2, C16.2, C17.2, C18.2, C19.2, C20.2, C21.2, C22.2, C23.2, C24.2, D1.2 (A), D3.1 (K), D4.1 (K), D5.1 (K), D6.1 (K), D7.1 (K), D8.3 (A), J1.2, J2.3, J3.3, J4.3, J5.2, J5.10, JP3.2, JP4.2, R3.2, R4.2, SW1.2, SW2.2, TP6.1, U1.2 (GND), U2.2 (GND), U3.19 (VSSA), U3.23 (VSS), U3.35 (VSS), U3.47 (VSS), U4.2 (GND), U5.1 (SDO/SA0), U5.2 (SDx), U5.3 (SCx), U5.6 (GND), U5.7 (GND), Y1.2 (GND), Y1.4 (GND)
I2C_SCL: R13.2, U3.39 (PA15), U5.13 (SCL)
I2C_SDA: R14.2, U3.44 (PB7), U5.14 (SDA)
IMU_INT1: U3.42 (PB5), U5.4 (INT1)
IMU_INT2: U3.46 (PB9), U5.9 (INT2)
LED_CANRX: R9.1, U3.29 (PB15)
LED_CANRX_A: D7.2 (A), R9.2
LED_CANTX: R8.1, U3.28 (PB14)
LED_CANTX_A: D6.2 (A), R8.2
LED_FAULT: R7.1, U3.27 (PB13)
LED_FAULT_A: D5.2 (A), R7.2
LED_STATUS: R6.1, U3.26 (PB12)
LED_STATUS_A: D4.2 (A), R6.2
NODE_ID0: JP3.1, U3.22 (PB10)
NODE_ID1: JP4.1, U3.25 (PB11)
NRST: C15.1, J4.5, SW1.1, U3.7 (PG10-NRST)
OSC_IN: C16.1, U3.5 (PF0-OSC_IN), Y1.3
OSC_OUT: C17.1, U3.6 (PF1-OSC_OUT), Y1.1
PWR_LED_A: D3.2 (A), R1.2
SWCLK: J4.2, U3.38 (PA14)
SWDIO: J4.4, U3.37 (PA13)
SWO: J4.6, U3.40 (PB3)
TERM_H: JP2.1, R11.2
TERM_L: JP2.2, R12.2
TERM_MID: C22.1, JP2.3, JP2.4
UART_RX: J5.4, U3.11 (PA3)
UART_TX: J5.3, U3.10 (PA2)
USER_BTN: C18.1, R5.2, SW2.1, U3.2 (PC13)
VIN_FUSED: D1.1 (K), D2.2 (A), F1.2
VIN_PROT: C1.1, C2.1, D2.1 (K), R2.1, TP3.1, U1.1 (+VIN)
VIN_RAW: F1.1, J1.1
VIN_SENSE: C6.1, R2.2, R3.1, U3.8 (PA0)

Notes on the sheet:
POWER INPUT, PROTECTION AND REGULATION
MICROCONTROLLER STM32G431CBT6 (clock, reset, boot, decoupling)
CAN INTERFACE (TJA1051T/3, ESD, switchable split termination)
IMU LSM6DS3TR-C (I2C1, addr 0x6A)
USER INTERFACE: LEDs, button, node-ID jumpers
DEBUG / EXPANSION CONNECTORS, MECHANICAL
DESIGN NOTES 1. Supply 8-18 V DC (12 V nominal). Reverse polarity: series Schottky D2; TVS D1 clamps transients and conducts on reverse polarity so PTC F1 trips. NOT load-dump rated. 2. R-78E5.0-0.5 needs >= 7 V in. +5V feeds the CAN transceiver VCC and the 3.3 V LDO. 3. FDCAN1 on PA11 (RX) / PA12 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

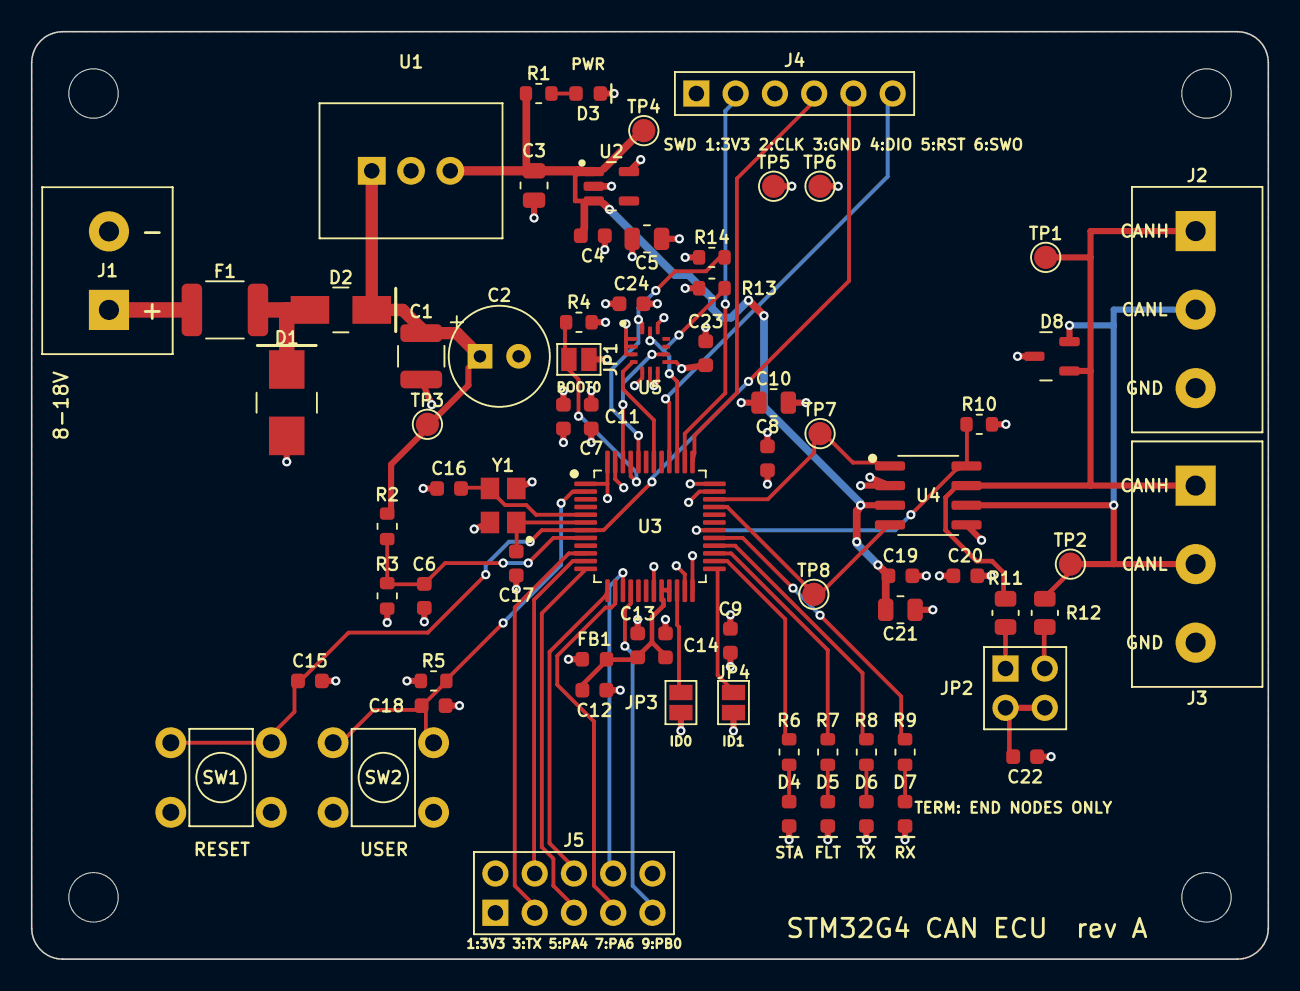
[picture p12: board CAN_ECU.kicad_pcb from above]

Board: 4 copper layers, 80.0 x 60.0 mm, 77 parts (0 on the bottom side), 46 nets.

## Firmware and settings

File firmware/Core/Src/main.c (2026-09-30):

/**
 * @file    main.c
 * @brief   STM32 CAN ECU firmware entry point (STM32G431CBT6, STM32Cube HAL).
 *
 * Start-up order:
 *   HAL + clocks (HSE 8 MHz -> PLL 170 MHz, fallback HSI16) -> UCPD dead-battery
 *   pull-downs off -> GPIO (transceiver kept silent) -> UART console -> reset
 *   cause -> watchdog (~1 s) -> ADC -> I2C + IMU -> FDCAN -> application loop.
 */
#include "main.h"

#include <stdio.h>

#include "app.h"
#include "board.h"
#include "can.h"
#include "debug.h"
#include "diagnostics.h"

I2C_HandleTypeDef  hi2c1;
IWDG_HandleTypeDef hiwdg;
volatile bool      g_hse_failed;

static reset_cause_t read_reset_cause(void)
{
    reset_cause_t c = RESET_CAUSE_UNKNOWN;
    if (__HAL_RCC_GET_FLAG(RCC_FLAG_IWDGRST))      c = RESET_CAUSE_IWDG;
    else if (__HAL_RCC_GET_FLAG(RCC_FLAG_WWDGRST)) c = RESET_CAUSE_WWDG;
    else if (__HAL_RCC_GET_FLAG(RCC_FLAG_LPWRRST)) c = RESET_CAUSE_LOW_POWER;
    else if (__HAL_RCC_GET_FLAG(RCC_FLAG_SFTRST))  c = RESET_CAUSE_SOFTWARE;
    else if (__HAL_RCC_GET_FLAG(RCC_FLAG_OBLRST))  c = RESET_CAUSE_OPTION_BYTE;
    else if (__HAL_RCC_GET_FLAG(RCC_FLAG_BORRST))  c = RESET_CAUSE_POWER_ON;
    else if (__HAL_RCC_GET_FLAG(RCC_FLAG_PINRST))  c = RESET_CAUSE_PIN;
    __HAL_RCC_CLEAR_RESET_FLAGS();
    return c;
}

static bool i2c1_init(void)
{
    hi2c1.Instance = I2C1;
    hi2c1.Init.Timing = 0x10320309;          /* 400 kHz @ I2CCLK = HSI16 (RM0440 example) */
    hi2c1.Init.OwnAddress1 = 0;
    hi2c1.Init.AddressingMode = I2C_ADDRESSINGMODE_7BIT;
    hi2c1.Init.DualAddressMode = I2C_DUALADDRESS_DISABLE;
    hi2c1.Init.OwnAddress2 = 0;
    hi2c1.Init.OwnAddress2Masks = I2C_OA2_NOMASK;
    hi2c1.Init.GeneralCallMode = I2C_GENERALCALL_DISABLE;
    hi2c1.Init.NoStretchMode = I2C_NOSTRETCH_DISABLE;
    if (HAL_I2C_Init(&hi2c1) != HAL_OK) return false;
    if (HAL_I2CEx_ConfigAnalogFilter(&hi2c1, I2C_ANALOGFILTER_ENABLE) != HAL_OK) return false;
    return HAL_I2CEx_ConfigDigitalFilter(&hi2c1, 0) == HAL_OK;
}

static void iwdg_init(void)
{
    /* LSI ~32 kHz / 32 = 1 kHz -> reload 1000 = ~1.0 s (LSI tolerance applies) */
    hiwdg.Instance = IWDG;
    hiwdg.Init.Prescaler = IWDG_PRESCALER_32;
    hiwdg.Init.Window = IWDG_WINDOW_DISABLE;
    hiwdg.Init.Reload = 1000;
    __HAL_DBGMCU_FREEZE_IWDG();              /* do not reset while halted in the debugger */
    if (HAL_IWDG_Init(&hiwdg) != HAL_OK) {
        Error_Handler();
    }
}

int main(void)
{
    HAL_Init();
    bool hse_ok = SystemClock_Config();
    HAL_PWREx_DisableUCPDDeadBattery();      /* PB4/PB6 UCPD pull-downs off */
    board_gpio_init();
    (void)debug_init();
    reset_cause_t cause = read_reset_cause();
    iwdg_init();
    if (!board_adc_init()) {
        printf("ADC init failed\r\n");
    }
    if (!i2c1_init()) {
        printf("I2C init failed\r\n");
    }
    uint8_t node = board_node_id();
    if (!can_init(node)) {
        printf("FDCAN init failed\r\n");
        Error_Handler();
    }
    app_init(node, cause, hse_ok);

    for (;;) {
        if (g_hse_failed) {
            g_hse_failed = false;
            (void)SystemClock_Config();        /* rebuild PLL from HSI16 */
            app_note_hse_failure();
        }
        app_run();
        if (app_alive(HAL_GetTick())) {
            (void)HAL_IWDG_Refresh(&hiwdg);
        }
    }
}

/**
 * HSE 8 MHz / M2 * N85 / R2 = 170 MHz, voltage range 1 boost, 4 wait states.
 * If the crystal does not start, the same PLL is built from HSI16 / M4.
 * FDCAN, USART2 and ADC run from PCLK1/HCLK = 170 MHz in both cases, so the
 * CAN bit timing is unchanged (HSI16 accuracy is +-1 %: marginal for CAN,
 * therefore flagged as FAULT_HSE).
 */
bool SystemClock_Config(void)
{
    RCC_OscInitTypeDef o = {0};
    RCC_ClkInitTypeDef c = {0};
    bool hse_ok = true;

    HAL_PWREx_ControlVoltageScaling(PWR_REGULATOR_VOLTAGE_SCALE1_BOOST);

    o.OscillatorType = RCC_OSCILLATORTYPE_HSE | RCC_OSCILLATORTYPE_HSI;
    o.HSEState = g_hse_failed ? RCC_HSE_OFF : RCC_HSE_ON;
    o.HSIState = RCC_HSI_ON;
    o.HSICalibrationValue = RCC_HSICALIBRATION_DEFAULT;
    o.PLL.PLLState = RCC_PLL_ON;
    o.PLL.PLLSource = RCC_PLLSOURCE_HSE;
    o.PLL.PLLM = RCC_PLLM_DIV2;
    o.PLL.PLLN = 85;
    o.PLL.PLLP = RCC_PLLP_DIV2;
    o.PLL.PLLQ = RCC_PLLQ_DIV2;
    o.PLL.PLLR = RCC_PLLR_DIV2;
    if (g_hse_failed || HAL_RCC_OscConfig(&o) != HAL_OK) {
        hse_ok = false;
        o.OscillatorType = RCC_OSCILLATORTYPE_HSI;
        o.HSEState = RCC_HSE_OFF;
        o.PLL.PLLSource = RCC_PLLSOURCE_HSI;
        o.PLL.PLLM = RCC_PLLM_DIV4;
        if (HAL_RCC_OscConfig(&o) != HAL_OK) {
            Error_Handler();
        }
    }
    c.ClockType = RCC_CLOCKTYPE_HCLK | RCC_CLOCKTYPE_SYSCLK | RCC_CLOCKTYPE_PCLK1 | RCC_CLOCKTYPE_PCLK2;
    c.SYSCLKSource = RCC_SYSCLKSOURCE_PLLCLK;
    c.AHBCLKDivider = RCC_SYSCLK_DIV1;
    c.APB1CLKDivider = RCC_HCLK_DIV1;
    c.APB2CLKDivider = RCC_HCLK_DIV1;
    if (HAL_RCC_ClockConfig(&c, FLASH_LATENCY_4) != HAL_OK) {
        Error_Handler();
    }
    if (hse_ok) {
        HAL_RCC_EnableCSS();                 /* HSE failure -> NMI -> HAL_RCC_CSSCallback */
    }
    return hse_ok;
}

void HAL_RCC_CSSCallback(void)
{
    g_hse_failed = true;                     /* hardware already switched SYSCLK to HSI16 */
}

void Error_Handler(void)
{
    __disable_irq();
    /* FAULT LED on, STATUS off; the watchdog resets the MCU after ~1 s */
    HAL_GPIO_WritePin(LED_FAULT_PORT, LED_FAULT_PIN, GPIO_PIN_SET);
    HAL_GPIO_WritePin(LED_STATUS_PORT, LED_STATUS_PIN, GPIO_PIN_RESET);
    HAL_GPIO_WritePin(CAN_S_PORT, CAN_S_PIN, GPIO_PIN_SET);   /* transceiver silent */
    for (;;) {
    }
}

#ifdef USE_FULL_ASSERT
void assert_failed(uint8_t *file, uint32_t line)
{
    printf("assert failed %s:%lu\r\n", (const char *)file, (unsigned long)line);
    Error_Handler();
}
#endif

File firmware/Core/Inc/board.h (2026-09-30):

/**
 * @file    board.h
 * @brief   Board pin map (rev A) and low-level board helpers.
 *          Must match hardware/gen/design.py and docs/PIN_MAPPING.md.
 */
#ifndef BOARD_H
#define BOARD_H

#include <stdbool.h>
#include <stdint.h>
#include "main.h"

/* LEDs: active high (MCU -> 680R -> LED -> GND) */
#define LED_STATUS_PORT   GPIOB
#define LED_STATUS_PIN    GPIO_PIN_12     /* green  D4 */
#define LED_FAULT_PORT    GPIOB
#define LED_FAULT_PIN     GPIO_PIN_13     /* red    D5 */
#define LED_CANTX_PORT    GPIOB
#define LED_CANTX_PIN     GPIO_PIN_14     /* yellow D6 */
#define LED_CANRX_PORT    GPIOB
#define LED_CANRX_PIN     GPIO_PIN_15     /* orange D7 */

/* USER button SW2: active low, 10k pull-up + 100 nF on board */
#define BTN_USER_PORT     GPIOC
#define BTN_USER_PIN      GPIO_PIN_13

/* CAN transceiver TJA1051T/3 pin 8 "S": HIGH = silent (10k pull-up), LOW = normal */
#define CAN_S_PORT        GPIOA
#define CAN_S_PIN         GPIO_PIN_8

/* Node ID solder jumpers to GND, internal pull-ups: closed = bit set */
#define NODE_ID0_PORT     GPIOB
#define NODE_ID0_PIN      GPIO_PIN_10     /* JP3 */
#define NODE_ID1_PORT     GPIOB
#define NODE_ID1_PIN      GPIO_PIN_11     /* JP4 */

/* IMU interrupt lines (inputs; firmware polls the status register) */
#define IMU_INT1_PORT     GPIOB
#define IMU_INT1_PIN      GPIO_PIN_5
#define IMU_INT2_PORT     GPIOB
#define IMU_INT2_PIN      GPIO_PIN_9

/* VIN sense: PA0 = ADC1_IN1, divider 100k / 15k -> ratio 7.667 */
#define VIN_DIV_NUM       115u
#define VIN_DIV_DEN       15u

typedef enum { LED_STATUS = 0, LED_FAULT, LED_CANTX, LED_CANRX, LED_COUNT } led_t;

void     board_gpio_init(void);
void     board_led(led_t led, bool on);
bool     board_button_pressed(void);
uint8_t  board_node_id(void);
void     board_can_transceiver_normal(bool normal);

bool     board_adc_init(void);
uint16_t board_vin_mv(void);        /* 0 on ADC error */
int16_t  board_mcu_temp_c(void);    /* INT16_MIN on ADC error */

#endif /* BOARD_H */

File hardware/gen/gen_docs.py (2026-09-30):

"""
gen_docs.py - documents and figures derived directly from the design data
(so they cannot drift from the KiCad files):
  docs/PIN_MAPPING.md, docs/COMPONENTS.md, docs/VALIDATION_REPORT.md,
  docs/img/*.png (block diagram, power tree, placement, copper layers)
"""
import csv
import io
import json
import os
import subprocess
import sys
from contextlib import redirect_stdout

import matplotlib
matplotlib.use("Agg")
import matplotlib.pyplot as plt
from matplotlib.patches import FancyBboxPatch

from design import PARTS
from lib import build_symbols, build_footprints
from board import PLACEMENT, courtyard, BX1, BY1, BX2, BY2

ROOT = "/home/claude/stm32-can-ecu"
DOCS = os.path.join(ROOT, "docs")
IMG = os.path.join(DOCS, "img")
SYMS = build_symbols()
FPS = build_footprints()

MCU_FUNC = {
    "PC13": "USER button SW2 (active low, ext. 10k pull-up)", "PF0-OSC_IN": "HSE 8 MHz crystal Y1",
    "PF1-OSC_OUT": "HSE 8 MHz crystal Y1", "PG10-NRST": "Reset: SW1, C15 100 nF, SWD pin 5",
    "PA0": "ADC1_IN1 - VIN sense divider 100k/15k", "PA2": "USART2_TX (AF7) debug console -> J5.3",
    "PA3": "USART2_RX (AF7) debug console -> J5.4", "PA4": "Expansion J5.5 (GPIO/ADC/DAC)",
    "PA5": "Expansion J5.6", "PA6": "Expansion J5.7", "PA7": "Expansion J5.8", "PB0": "Expansion J5.9",
    "PB10": "NODE_ID bit0 - solder jumper JP3 to GND (internal pull-up)",
    "PB11": "NODE_ID bit1 - solder jumper JP4 to GND (internal pull-up)",
    "PB12": "LED STATUS (green) via 680R", "PB13": "LED FAULT (red) via 680R",
    "PB14": "LED CAN-TX (yellow) via 680R", "PB15": "LED CAN-RX (orange) via 680R",
    "PA8": "CAN transceiver S (silent) - 10k pull-up, LOW = normal",
    "PA11": "FDCAN1_RX (AF9) <- TJA1051 RXD", "PA12": "FDCAN1_TX (AF9) -> TJA1051 TXD",
    "PA13": "SWDIO (J4.4)", "PA14": "SWCLK (J4.2)", "PA15": "I2C1_SCL (AF4) - IMU, 4k7 pull-up",
    "PB3": "SWO trace output (J4.6)", "PB5": "IMU INT1 (accel data-ready)", "PB7": "I2C1_SDA (AF4) - IMU, 4k7 pull-up",
    "PB8-BOOT0": "BOOT0: 10k pull-down, JP1 to 3V3 = system bootloader", "PB9": "IMU INT2 (spare)",
    "VBAT": "+3V3 (no backup battery), 100 nF", "VDD": "+3V3, 100 nF per pin + 4.7 uF bulk",
    "VSS": "GND", "VSSA": "GND", "VDDA": "+3V3A (ferrite FB1 + 1 uF + 100 nF)", "VREF+": "+3V3A, 100 nF",
}


def pin_mapping():
    mcu = PARTS["U3"]
    sym = SYMS["STM32G431CBTx"]
    names = {p.num: p.name for p in sym.pins}
    L = ["# MCU pin mapping - STM32G431CBT6 (LQFP48)", "",
         "Generated from `hardware/gen/design.py` (single source of truth for schematic, PCB and firmware "
         "`Core/Inc/board.h`). Pin numbers/names were checked against ST datasheet DS12589 (LQFP48 pinout). "
         "Unused pins are unconnected on the PCB and configured as analog inputs by the firmware.", "",
         "| Pin | Name | Net | Function |", "|---:|---|---|---|"]
    for n in range(1, 49):
        nm = names.get(str(n), "?")
        net = mcu.pins.get(str(n))
        base = nm.split("/")[0]
        func = MCU_FUNC.get(nm, MCU_FUNC.get(base, "not connected (analog input)" if net is None else ""))
        L.append(f"| {n} | {nm} | {net or '-'} | {func} |")
    L += ["", "## Alternate-function summary", "",
          "| Peripheral | Signal | Pin | AF |", "|---|---|---|---|",
          "| FDCAN1 | RX | PA11 | AF9 |", "| FDCAN1 | TX | PA12 | AF9 |",
          "| I2C1 | SCL | PA15 | AF4 |", "| I2C1 | SDA | PB7 | AF4 |",
          "| USART2 | TX | PA2 | AF7 |", "| USART2 | RX | PA3 | AF7 |",
          "| SWD | SWDIO / SWCLK / SWO | PA13 / PA14 / PB3 | AF0 (reset default) |",
          "| ADC1 | IN1 (VIN sense) | PA0 | analog |", "",
          "**Why no USB:** on the STM32G431 the only FDCAN1 pin pair that does not collide with other "
          "functions here is PA11/PA12 - the same pins as USB DM/DP. The alternative FDCAN1 pins PB8/PB9 "
          "would put CAN RX on the BOOT0 pin (PB8), which is a known source of boot problems. Rev A therefore "
          "uses PA11/PA12 for CAN and provides a 3.3 V UART on J5 instead of USB.", ""]
    L += ["## Connectors", ""]
    for ref, title in [("J1", "Power input (5.08 mm screw terminal)"), ("J2", "CAN bus A (5.08 mm, 3-pole)"),
                       ("J3", "CAN bus B (5.08 mm, 3-pole, parallel to J2 for daisy-chaining)"),
                       ("J4", "SWD debug (1x6 2.54 mm, ST-LINK/Nucleo CN4 order)"),
                       ("J5", "Expansion / UART (2x5 2.54 mm)"), ("JP2", "CAN termination (2x2 2.54 mm, fit 2 shunts: 1-3 and 2-4)")]:
        p = PARTS[ref]
        L += [f"### {ref} - {title}", "", "| Pin | Net |", "|---:|---|"]
        for k in sorted(p.pins, key=int):
            L.append(f"| {k} | {p.pins[k]} |")
        L.append("")
    L += ["## Jumpers", "", "| Ref | Function | Open (default) | Closed |", "|---|---|---|---|",
          "| JP1 | BOOT0 | boot from flash | ST system bootloader (UART/FDCAN/I2C/SPI) |",
          "| JP2 | CAN termination (2 shunts) | no termination | 2 x 60.4 R split + 4.7 nF |",
          "| JP3 | NODE_ID bit 0 (PB10) | 0 | 1 |", "| JP4 | NODE_ID bit 1 (PB11) | 0 | 1 |", "",
          "Node ID = JP4*2 + JP3 -> 0..3. Two boards must have **different** node IDs "
          "(e.g. board A: both open = node 0; board B: JP3 closed = node 1).", ""]
    open(os.path.join(DOCS, "PIN_MAPPING.md"), "w").write("\n".join(L))


VERIFY = {
    "LQFP-48_7x7mm_P0.5mm": "Generated to IPC-7351-like dimensions (pads 1.475 x 0.3 at +-4.1625). Compare with KiCad Package_QFP:LQFP-48_7x7mm_P0.5mm.",
    "LGA-14_3x2.5mm_P0.5mm_LayoutBorder3x4y": "**VERIFY** against ST LSM6DS3TR-C land-pattern recommendation (pads 0.5 x 0.25 mm). Pin-1 orientation is critical.",
    "SOIC-8_3.9x4.9mm_P1.27mm": "Standard JEDEC MS-012 land pattern.",
    "Converter_DCDC_RECOM_R-78E-0.5_THT": "**VERIFY** pin pitch (2.54 mm) and body side against the RECOM drawing; 6.5 mm keep-out reserved both sides.",
    "Crystal_SMD_3225-4Pin_3.2x2.5mm": "Standard 3225 4-pad; confirm pad 1/3 = crystal, 2/4 = GND for the chosen part.",
    "SOT-23": "**VERIFY** PESD1CAN pinout (1 = CANH/line, 2 = CANL/line, 3 = common) - symmetric part, swapping 1/2 is harmless.",
    "SOT-23-5": "AP2112K SOT-23-5 pinout checked (1 VIN, 2 GND, 3 EN, 4 NC, 5 VOUT).",
    "TerminalBlock_1x02_P5.08mm_Horizontal": "**VERIFY** hole size/pitch vs. the terminal block actually bought (Phoenix MKDS 1,5/2-5,08 style).",
    "TerminalBlock_1x03_P5.08mm_Horizontal": "**VERIFY** as above (3-pole).",
    "Fuse_1812_4532Metric": "Generic 1812 PTC land pattern.",
}
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

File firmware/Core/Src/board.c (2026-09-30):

/**
 * @file    board.c
 * @brief   GPIO configuration, LEDs, button, node ID, ADC measurements.
 */
#include "board.h"

ADC_HandleTypeDef hadc1;

static const struct { GPIO_TypeDef *port; uint16_t pin; } s_led[LED_COUNT] = {
    { LED_STATUS_PORT, LED_STATUS_PIN }, { LED_FAULT_PORT, LED_FAULT_PIN },
    { LED_CANTX_PORT, LED_CANTX_PIN },   { LED_CANRX_PORT, LED_CANRX_PIN },
};

void board_gpio_init(void)
{
    GPIO_InitTypeDef g = {0};
    __HAL_RCC_GPIOA_CLK_ENABLE();
    __HAL_RCC_GPIOB_CLK_ENABLE();
    __HAL_RCC_GPIOC_CLK_ENABLE();
    __HAL_RCC_GPIOF_CLK_ENABLE();

    /* outputs: safe levels first */
    HAL_GPIO_WritePin(GPIOB, LED_STATUS_PIN | LED_FAULT_PIN | LED_CANTX_PIN | LED_CANRX_PIN, GPIO_PIN_RESET);
    HAL_GPIO_WritePin(CAN_S_PORT, CAN_S_PIN, GPIO_PIN_SET);          /* transceiver silent */

    g.Pin = LED_STATUS_PIN | LED_FAULT_PIN | LED_CANTX_PIN | LED_CANRX_PIN;
    g.Mode = GPIO_MODE_OUTPUT_PP;
    g.Pull = GPIO_NOPULL;
    g.Speed = GPIO_SPEED_FREQ_LOW;
    HAL_GPIO_Init(GPIOB, &g);

    g.Pin = CAN_S_PIN;
    HAL_GPIO_Init(CAN_S_PORT, &g);

    g.Pin = BTN_USER_PIN;
    g.Mode = GPIO_MODE_INPUT;
    g.Pull = GPIO_NOPULL;                                             /* external 10k */
    HAL_GPIO_Init(BTN_USER_PORT, &g);

    g.Pin = NODE_ID0_PIN | NODE_ID1_PIN;
    g.Pull = GPIO_PULLUP;
    HAL_GPIO_Init(GPIOB, &g);

    g.Pin = IMU_INT1_PIN | IMU_INT2_PIN;
    g.Pull = GPIO_PULLDOWN;                                           /* IMU INT is push-pull */
    HAL_GPIO_Init(GPIOB, &g);

    /* unused / not-connected pins -> analog (lowest power, no floating inputs).
     * Expansion header pins PA4..PA7, PB0 are also left analog until used.   */
    g.Mode = GPIO_MODE_ANALOG;
    g.Pull = GPIO_NOPULL;
    g.Pin = GPIO_PIN_1 | GPIO_PIN_4 | GPIO_PIN_5 | GPIO_PIN_6 | GPIO_PIN_7 | GPIO_PIN_9 | GPIO_PIN_10;
    HAL_GPIO_Init(GPIOA, &g);
    g.Pin = GPIO_PIN_0 | GPIO_PIN_1 | GPIO_PIN_2 | GPIO_PIN_4 | GPIO_PIN_6;
    HAL_GPIO_Init(GPIOB, &g);
    g.Pin = GPIO_PIN_14 | GPIO_PIN_15;
    HAL_GPIO_Init(GPIOC, &g);
}

void board_led(led_t led, bool on)
{
    if (led < LED_COUNT) {
        HAL_GPIO_WritePin(s_led[led].port, s_led[led].pin, on ? GPIO_PIN_SET : GPIO_PIN_RESET);
    }
}

bool board_button_pressed(void)
{
    return HAL_GPIO_ReadPin(BTN_USER_PORT, BTN_USER_PIN) == GPIO_PIN_RESET;
}

uint8_t board_node_id(void)
{
    uint8_t id = 0;
    if (HAL_GPIO_ReadPin(NODE_ID0_PORT, NODE_ID0_PIN) == GPIO_PIN_RESET) id |= 1u;
    if (HAL_GPIO_ReadPin(NODE_ID1_PORT, NODE_ID1_PIN) == GPIO_PIN_RESET) id |= 2u;
    return id;
}

void board_can_transceiver_normal(bool normal)
{
    HAL_GPIO_WritePin(CAN_S_PORT, CAN_S_PIN, normal ? GPIO_PIN_RESET : GPIO_PIN_SET);
}

/* ------------------------------------------------------------------ ADC */
bool board_adc_init(void)
{
    hadc1.Instance = ADC1;
    hadc1.Init.ClockPrescaler = ADC_CLOCK_SYNC_PCLK_DIV4;     /* 170/4 = 42.5 MHz */
    hadc1.Init.Resolution = ADC_RESOLUTION_12B;
    hadc1.Init.DataAlign = ADC_DATAALIGN_RIGHT;
    hadc1.Init.GainCompensation = 0;
    hadc1.Init.ScanConvMode = ADC_SCAN_DISABLE;
    hadc1.Init.EOCSelection = ADC_EOC_SINGLE_CONV;
    hadc1.Init.LowPowerAutoWait = DISABLE;
    hadc1.Init.ContinuousConvMode = DISABLE;
    hadc1.Init.NbrOfConversion = 1;
    hadc1.Init.DiscontinuousConvMode = DISABLE;
    hadc1.Init.ExternalTrigConv = ADC_SOFTWARE_START;
    hadc1.Init.ExternalTrigConvEdge = ADC_EXTERNALTRIGCONVEDGE_NONE;
    hadc1.Init.DMAContinuousRequests = DISABLE;
    hadc1.Init.Overrun = ADC_OVR_DATA_OVERWRITTEN;
    hadc1.Init.OversamplingMode = DISABLE;
    if (HAL_ADC_Init(&hadc1) != HAL_OK) {
        return false;
    }
    return HAL_ADCEx_Calibration_Start(&hadc1, ADC_SINGLE_ENDED) == HAL_OK;
}

static bool adc_read(uint32_t channel, uint32_t *raw)
{
    ADC_ChannelConfTypeDef c = {0};
    c.Channel = channel;
    c.Rank = ADC_REGULAR_RANK_1;
    c.SamplingTime = ADC_SAMPLETIME_247CYCLES_5;              /* >5 us for VREFINT/TS */
    c.SingleDiff = ADC_SINGLE_ENDED;
    c.OffsetNumber = ADC_OFFSET_NONE;
    c.Offset = 0;
    if (HAL_ADC_ConfigChannel(&hadc1, &c) != HAL_OK) return false;
    if (HAL_ADC_Start(&hadc1) != HAL_OK) return false;
    if (HAL_ADC_PollForConversion(&hadc1, 2) != HAL_OK) {
        (void)HAL_ADC_Stop(&hadc1);
        return false;
    }
    *raw = HAL_ADC_GetValue(&hadc1);
    (void)HAL_ADC_Stop(&hadc1);
    return true;
}

static uint32_t vdda_mv(void)
{
    uint32_t vref = 0;
    if (!adc_read(ADC_CHANNEL_VREFINT, &vref) || vref == 0u) {
        return 3300u;                                       /* nominal fallback */
    }
    return __HAL_ADC_CALC_VREFANALOG_VOLTAGE(vref, ADC_RESOLUTION_12B);
}

uint16_t board_vin_mv(void)
{
    uint32_t raw = 0;
    uint32_t vdda = vdda_mv();
    if (!adc_read(ADC_CHANNEL_1, &raw)) {
        return 0u;
    }
    uint32_t pin_mv = (raw * vdda) / 4095u;
    return (uint16_t)((pin_mv * VIN_DIV_NUM) / VIN_DIV_DEN);
}
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

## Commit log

2026-09-30 Add LICENSE file with project licensing information
    Added a comprehensive LICENSE file detailing the licensing for hardware, software, documentation, and third-party materials.
2026-09-30 Add LICENSE file with project licensing details
    Added licensing information for hardware, software, documentation, and third-party materials.
